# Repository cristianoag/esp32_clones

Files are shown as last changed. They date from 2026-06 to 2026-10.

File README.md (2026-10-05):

# The Retro Hacker Clone Series

The Retro Hacker Clone Series brings together hardware designs and source-available firmware to recreate and emulate classic Brazilian computers from the 80s using modern ESP32-S3 based hardware.

 The board is designed to feel like a small retro computer rather than a bare dev board, and the firmwares are built to be practical, tweakable, and easy to build from a standard Git checkout.

At the moment the series includes four emulator builds on the same ESP32-S3 board:

| Firmware | Covered machines | Project |
| --- | --- | --- |
| CP400 | Prologica CP400 / CoCo 2 | [Setup guide](software/esp32_cp400_emulator/README.md) and [change log](software/esp32_cp400_emulator/docs/log.md) |
| MSX | MSX1, MSX2, and MSX2+ | [Setup guide](software/esp32_msx_emulator/README.md) and [change log](software/esp32_msx_emulator/docs/log.md) |
| TK90X / TK95 | Microdigital TK90X (48 KiB) and TK95 | [Setup guide](software/esp32_tk95_emulator/README.md) and [change log](software/esp32_tk95_emulator/docs/log.md) |
| Apple II | Generic Apple II+ and original Apple IIe | [Setup guide](software/esp32_apple2_emulator/README.md) and [change log](software/esp32_apple2_emulator/docs/log.md) |

All four builds share the same board, VGA output, USB keyboard input, SD-card storage, and a simple F12 menu for setup and firmware updates.

### Switching emulators

With the current updater and shared dual 4 MiB OTA layout installed, open
**F12 > Firmware update** in any emulator and select another emulator's
`.FLH` package. For example, MSX can install CP400, and CP400 can then
install Apple II. No renaming is needed. Copy the packages to the FAT32
card root (required by CP400's file picker), prepare the destination
emulator's ROMs using its setup guide, confirm the update and keep power
connected until the board restarts. The original FLH stays on the card.

Build packages with `make firmware` in each firmware folder. Older MSX,
TK and Apple updaters reject other emulator filenames: first update to
the current build of the **same** emulator. Older CP400 installations use
a smaller partition layout and require a **one-time UART upload** of a
current build before switching via SD. FLH updates replace only the
application, not the bootloader or partition table. Use current builds
for every destination so switching remains available after reboot.
Checksums detect corruption, not authenticity; install only trusted
firmware built for this board.

After building all four packages, run
`powershell -ExecutionPolicy Bypass -File .\software\Test-FirmwareCompatibility.ps1`
to check the shared layout and all 16 source/destination combinations
against mock OTA storage. Physical-board switching still needs validation.

## Why this exists

The goal is not to produce a display piece. This is meant to be a useful, buildable retro-computing emulation based platform: something that captures the character of a Brazilian 80s machine without needing a pile of original hardware on the bench.

The project sits between hardware design, emulator work, and preservation. It keeps the board layout, software, and documentation together in one place so someone can build, test, and modify it without digging through a dozen disconnected repos.

## CP400

The Prologica CP400 was one of the more recognizable Brazilian home computers of the 1980s. It was compatible with the Tandy/Radio Shack TRS-80 Color Computer 2, but it had its own industrial design, Brazilian-language software ecosystem, and local hardware expectations.

The [CP400 firmware](software/esp32_cp400_emulator/README.md) recreates that environment on ESP32-S3 hardware, including MC6809 emulation, VGA output, native USB keyboard support, joystick inputs, SD storage, virtual floppy handling, and the F12 configuration/update menu.

## MSX

The MSX has a very special place in Brazilian computing history. It officially arrived in Brazil in 1985 through two locally produced machines: the HotBit, from Sharp/Epcom, and the Expert, from Gradiente. At a time when Brazil’s computer market was heavily restricted and imported machines were difficult and expensive to obtain, the MSX became one of the country’s most important home-computing platforms. Its standardized architecture, large software library, expandability, and built-in BASIC introduced an entire generation not only to games, but also to programming, electronics, and computer technology. 

The [MSX firmware](software/esp32_msx_emulator/README.md) runs the original fMSX core on the same shared board. It includes multiple BIOS profiles for Omega MSX2+, Gradiente Expert 1.1, Sharp Hotbit 1.2, and Panasonic FS-A1WSX / FS-A1F / FS-A1FX.

The software supports the core MSX experience with USB keyboard input, graphics, sound, cartridge booting, and firmware updates through the on-screen menu. and... USB joystick support, of course.

The F12 Media menu attaches writable `.dsk` images to drives A/B and read-only `.cas` tapes, with ejection, tape rewind and optional saved boot defaults. Disk access requires a compatible user-supplied disk BIOS; see the [disk and tape setup guide](software/esp32_msx_emulator/README.md#disk-and-tape-images).

## TK90X / TK95

The Microdigital TK90X and TK95 brought the ZX Spectrum family of computers to Brazilian homes. The [TK firmware](software/esp32_tk95_emulator/README.md) emulates the TK95 and 48 KiB TK90X on the same shared ESP32-S3 board, using
the cycle-stepped chips Z80 core.

The firmware includes VGA output, USB keyboard input, beeper audio and two USB joystick ports with calibration and selectable Kempston, Sinclair 1/2 or Cursor interfaces. The F12 menu brings together machine and ROM selection, 50/60 Hz Microdigital ULA timing, Portuguese/Spanish ROM language selection, sound and volume, saved boot defaults, reset options and firmware updates.

Media support includes read-only standard `.tap` playback and loading 48K `.sna` and `.z80` snapshots. Supply legally obtained, raw 16 KiB ROMs at `tk\bios\tk95.rom` and `tk\bios\tk90.rom` on the FAT32 card; the `tk` folder can sit alongside `msx` and `cp400`. No ROM bytes are embedded in the firmware.

See the [SD card and ROM setup](software/esp32_tk95_emulator/README.md#sd-card-and-roms) and [keyboard guide](software/esp32_tk95_emulator/README.md#keyboard-and-joysticks) for the original TK keyword-entry conventions.

The initial release does not include AY audio, Betadisk, TZX, tape recording or snapshot saving, and does not claim full cycle accuracy. 

## Apple II

The [Apple II firmware](software/esp32_apple2_emulator/README.md) adds generic
Apple II+ (64 KiB with language card) and original Apple IIe (128 KiB)
profiles. It follows the shared standalone PlatformIO, board-driver, F12
configuration and FLH firmware-update conventions.

The initial integration uses
[codesafe/ESP32-VGA_AppleII_Emulator](https://github.com/codesafe/ESP32-VGA_AppleII_Emulator)
as its starting reference, with a cycle-stepped NMOS 6502 and additional
IIe banking and display support. VGA preserves the full width of
80-column text; USB keyboard, calibrated joystick/paddle input, speaker
audio and two read-only NIB Disk II drives are included.

Supply machine and Disk II ROMs under `apple2/bios` on SD. No ROMs or games
are distributed. Enhanced IIe/65C02 and Brazilian TK2000, TK3000/Compact,
MC-4000/Exato and Exato IIe profiles are not claimed as supported without
their required hardware and verified ROMs. See the
[scope and limitations](software/esp32_apple2_emulator/README.md#supported-media-and-limitations).
Physical-board validation is still pending.

## Repository layout

```text
hardware/esp32_clones/          KiCad PCB and shared board files
hardware/esp32_clones/libraries Local KiCad symbols and footprints
hardware/esp32_clones/bom       Interactive BOM and BOM assets
hardware/cases/standard/       Parametric printed base, acrylic lid and manufacturing exports
software/esp32_cp400_emulator/  PlatformIO firmware for the CP400 build
software/esp32_msx_emulator/    MSX firmware and setup files
software/esp32_tk95_emulator/   TK90X/TK95 firmware and setup files
software/esp32_apple2_emulator/ Apple II+/original IIe firmware and setup files
images/                         Generated images and project documentation assets
```

## Board renderings

For the first enclosure prototype, see the
[standard case manufacturing files and engineering report](hardware/cases/standard/README.md).
It combines a printed base with side-loading M3 PCB nut traps, a snap-fit upper
shell, and a plain 3 mm acrylic lid seated in a recess. The report documents the
remaining physical-fit checks for components missing from the board STEP.

The Hotbit-inspired **Compact Classic C2** fits the same PCB in a
**124 x 74 x 39.1 mm** case, reducing the earlier Classic footprint by 26.9%.
It retains the miniature keyboard, photo-inspired colours and closed decorative
grille, with underside M3 cover screws. Use the matching
[base STL](hardware/cases/hb-8000/classic_base.stl) and
[upper STL](hardware/cases/hb-8000/classic_upper.stl); do not mix these with older
Classic or Wasteland halves. See the
[assembled/exploded preview](hardware/cases/hb-8000/classic_preview.png).
Print both STLs at 100%; the upper needs removable interior supports.
PCB screws remain M3 x 8 with 1 mm nylon washers; cover screws are M3 x 16,
with four M3 hex nuts for each set. Physical plug-fit and thermal tests are
still required; the decorative grille is not a ventilation opening.

The PCB below is the current KiCad board layout for the shared ESP32 clone board. The front and back views are generated directly from the project PCB.

<div align="center">
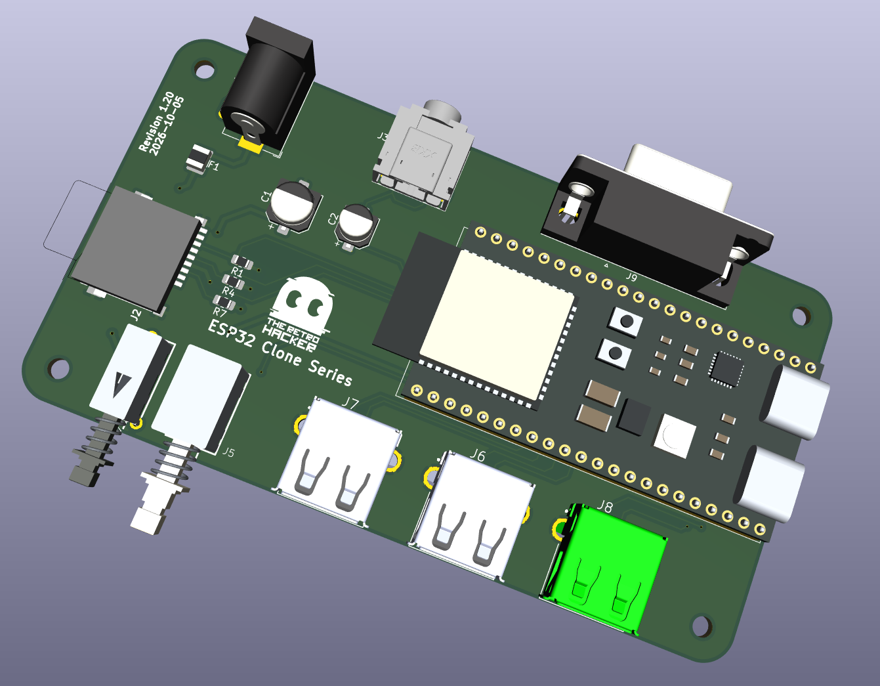
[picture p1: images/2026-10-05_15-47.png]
ESP32 clone board front
  
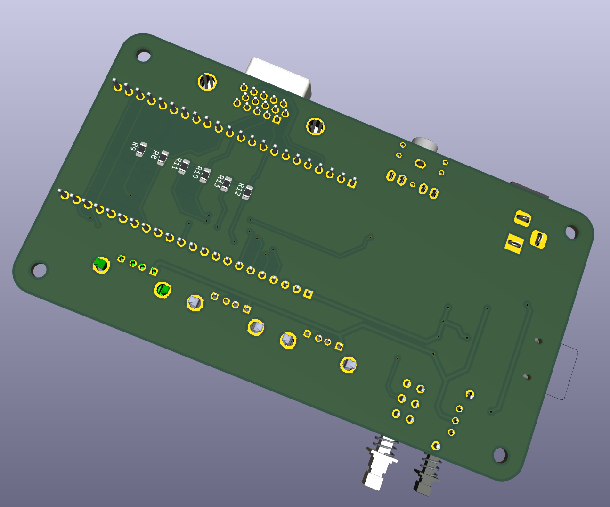
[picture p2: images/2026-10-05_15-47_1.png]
ESP32 clone board back
  
</div>

For the full component-by-component assembly view, open the [interactive BOM](https://htmlpreview.github.io/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).

## Hardware summary

The board is built around an ESP32-S3 DevKitC-style N16R8 module with 16 MB flash and 8 MB OPI PSRAM. It includes VGA output, a USB keyboard port, SD/MMC storage, a mono audio output, and a compact layout intended to behave more like a small computer than a bare dev board.

The shared board is used by all four firmware projects, and the pin mapping is documented in the [MSX hardware section](software/esp32_msx_emulator/README.md#hardware), the [TK hardware section](software/esp32_tk95_emulator/README.md#hardware) and the [Apple II hardware section](software/esp32_apple2_emulator/README.md#hardware).

## BOM and purchasing

This is the current BOM for the board as defined in the KiCad project. The table is meant to be a quick parts reference for ordering and build prep.

| Component | Description | Qty | Package | AliExpress |
| --- | --- | ---: | --- | --- |
| C1 | 220 µF electrolytic capacitor | 1 | 6.3x3 mm | [AliExpress](https://s.click.aliexpress.com/e/_c3vZZzuN) |
| C2 | 10 µF electrolytic capacitor | 1 | 5x4.5 mm | [AliExpress](https://s.click.aliexpress.com/e/_c3vZZzuN) |
| C4 | 100 nF ceramic capacitor | 1 | 0805 | [AliExpress](https://s.click.aliexpress.com/e/_c31gzw17) |
| C6 | 47 nF ceramic capacitor | 1 | 0805 | [AliExpress](https://s.click.aliexpress.com/e/_c31gzw17) |
| F1 | Resettable fuse / polyfuse | 1 | 1210 | [AliExpress](https://s.click.aliexpress.com/e/_c36cHi81) |
| J1 | DC barrel jack | 1 | Horizontal | [AliExpress](https://s.click.aliexpress.com/e/_c3D102dx) |
| J2 | Micro SD card socket | 1 | uSD | [AliExpress](https://s.click.aliexpress.com/e/_c3odXI41) |
| J3 | 3.5 mm audio jack | 1 | PJ-307 | [AliExpress](https://s.click.aliexpress.com/e/_c4DX94lF) |
| J4 | 12V power header / connector | 1 | PS-12E05 | [AliExpress](https://s.click.aliexpress.com/e/_c42cnGRn) |
| J5 | 5V power header / connector | 1 | PS-22F05 | [AliExpress](https://s.click.aliexpress.com/e/_c35YnsCh) |
| J6–J8 | USB-A connector | 3 | TE 6364372-2 | [AliExpress](https://s.click.aliexpress.com/e/_c4afTAHb) |
| J9 | DB15 video connector | 1 | D-sub 15-pin | [AliExpress](https://s.click.aliexpress.com/e/_c3K7eRWv) |
| R1, R4, R7 | 10 kΩ resistor | 3 | 0805 | [AliExpress](https://s.click.aliexpress.com/e/_c2zrvGiH) |
| R8, R10, R12 | 1.2 kΩ resistor | 3 | 0805 | [AliExpress](https://s.click.aliexpress.com/e/_c2zrvGiH) |
| R9, R11, R13 | 560 Ω resistor | 3 | 0805 | [AliExpress](https://s.click.aliexpress.com/e/_c2zrvGiH) |
| R2, R5 | 330 Ω resistor | 2 | 0805 | [AliExpress](https://s.click.aliexpress.com/e/_c2zrvGiH) |
| U1 | ESP32-S3-WROOM-1 module | 1 | ESP32-S3-WROOM-1 | [AliExpress](https://s.click.aliexpress.com/e/_c2uppnEv) |

## Firmware build notes

All three firmware projects use PlatformIO with the Arduino framework and a pinned `espressif32@6.11.0` platform. From the project directory you want to use, run:

```powershell
Set-Location .\software\esp32_cp400_emulator
# or:
# Set-Location .\software\esp32_msx_emulator
# or:
# Set-Location .\software\esp32_tk95_emulator

make firmware
```

The build produces FLH packages for each target; the project directories keep their own firmware images and configuration.
Each firmware directory includes its own board definitions and required
library sources and can be copied and compiled independently of the others.
All three still require PlatformIO and the configured ESP32 toolchain.

## ROMs and original software

Original CP400, CoCo, MSX, TK90X/TK95, ZX Spectrum, BASIC, cartridge, cassette, and floppy software may still be copyrighted. This repository is for original hardware, firmware, and project files. Use legally obtained ROMs and software images when needed.

The CP400 firmware loads its BIOS files from `software/esp32_cp400_emulator/sdcard/cp400/bios`. Copy the `cp400` folder to the root of the microSD card so the firmware can read the BASIC, Extended BASIC, and CP400 or CoCo disk controller ROM selected in the F12 menu.

## Historical notes

The CP400 was part of the wider Brazilian TRS-Color ecosystem, the MSX line became one of the most important home computer families in Brazil, and Microdigital's TK90X and TK95 connected Brazilian users to the ZX Spectrum ecosystem. This project sits at the intersection of those histories: a practical board, three emulator builds, and a small bit of preservation work for machines that still matter to a lot of people.

## References

- [Prologica CP-400](https://en.wikipedia.org/wiki/Prol%C3%B3gica_CP-400)
- [CP400](https://pt.wikipedia.org/wiki/CP400)
- [TRS-80 Color Computer](https://en.wikipedia.org/wiki/TRS-80_Color_Computer)
- [MSX](https://en.wikipedia.org/wiki/MSX)
- [fMSX by Marat Fayzullin](https://fms.komkon.org/fMSX/)
- [TK90X](https://en.wikipedia.org/wiki/TK90X)
- [TK95](https://en.wikipedia.org/wiki/TK95)
- [ESPectrum reference emulator](https://github.com/EremusOne/ESPectrum)
- [chips Z80 core](https://github.com/floooh/chips)
- [Prologica](https://pt.wikipedia.org/wiki/Prol%C3%B3gica)
- [Datassette](https://datassette.org/)

## License



All hardware and firmware binaries in this repository are released under the Creative Commons Attribution-NonCommercial-ShareAlike 4.0 International license. Personal builds and community tinkering are encouraged, but commercial use or resale requires explicit authorization from the author.

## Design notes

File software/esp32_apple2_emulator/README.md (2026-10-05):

# ESP32 Apple II+ / original Apple IIe

Standalone firmware for the shared Retro Hacker Clone Series ESP32-S3 N16R8
board. Firmware version: **1.03**. The CP400, MSX and TK firmware folders are
not needed to build or run it.

The initial profiles are **generic Apple II+** (48 KiB RAM plus a 16 KiB
language card) and **original Apple IIe** (128 KiB including the extended
80-column card). Both use a cycle-stepped **NMOS 6502**, not a 65C02.
Default: original IIe.

[codesafe/ESP32-VGA_AppleII_Emulator](https://github.com/codesafe/ESP32-VGA_AppleII_Emulator)
is the initial reference. Its II+ hardware is not sufficient for an IIe:
this integration adds IIe banking, internal firmware selection, 80-column
text and double-resolution graphics. The CPU is the licensed chips 6502,
following the TK firmware's cycle-stepped-core pattern. See
[dependency provenance](lib/README.md).

**Brazilian clone profiles are deferred.** TK2000 is not simply an Apple II
ROM replacement; TK3000 IIe/Compact require enhanced-machine and
clone-specific support. MC-4000/Exato and Exato IIe also need their own
verified ROMs and hardware profiles. They are not listed as supported
machines merely because they belong to the Apple family.

## Hardware

| Function | GPIO |
| --- | --- |
| VGA red low/high | 5 / 4 |
| VGA green low/high | 7 / 6 |
| VGA blue low/high | 9 / 8 |
| VGA HSYNC / VSYNC | 2 / 1 |
| Native USB keyboard D- / D+ | 19 / 20 |
| Low-speed USB joystick 1 D- / D+ | 15 / 16 |
| Low-speed USB joystick 2 D- / D+ | 17 / 18 |
| One-bit SD/MMC CMD / CLK / D0 | 38 / 39 / 40 |
| Mono PWM audio | 47 |
| Onboard RGB LED, disabled at startup | 48 |

Use the board's **UART connector** for upload and diagnostics. Native USB
is reserved for the keyboard; the board must supply VBUS. Joysticks use
the existing direct low-speed USB transport, not hubs or full-speed pads.

VGA uses a **640x240 framebuffer with hardware line doubling**. The
560x192 Apple picture is centered: 40-column text and 280-pixel graphics
are doubled horizontally; 80-column text and 560-pixel graphics retain
their full horizontal resolution. The F12 UI retains the familiar
320x240 logical layout. Set a widescreen monitor to 4:3/aspect mode.
The pinout and physical VGA timing remain compatible with the shared board.

## Build, test and upload

From this firmware directory:

```powershell
pio run
make test
make firmware
pio run -t upload
```

PlatformIO is pinned to `espressif32@6.11.0`. `make` finds PlatformIO's
usual Windows virtual environment. Native tests require G++ and
PowerShell on PATH. All libraries and the board definition are local.

`make firmware` packages and verifies `dist\ESP32_APPLE2-1.03.FLH` using
the shared decimal checksum + `-~` + ESP32-S3 application format.
Install over UART first to install the dual 4 MiB OTA partition layout.
Later updates use **F12 > Firmware update** and any compatible `.FLH`
package for CP400, MSX, TK95 or Apple II on SD, without renaming. Prepare
the destination emulator's ROMs before switching and put packages at the
card root so CP400's file picker can also find them. After restart, use
the destination's Firmware update menu to switch again.
The checksum is **not a signature**; use only trusted firmware for this
board. Keep power connected throughout; the original FLH is preserved.
An older Apple updater must first install the current Apple package to
remove its filename restriction. Older CP400 layouts require a one-time
UART upload of a current build; FLH cannot change the partition table.
Use current destination builds to retain cross-emulator updates.

## SD card and ROMs

Use FAT32 and put `sdcard\apple2` at the card root. It can coexist with
`cp400`, `msx` and `tk`:

```text
apple2\
  bios\
    apple2plus.rom    12,288 bytes, D000-FFFF
    apple2e.rom       16,384 bytes, C000-FFFF, ORIGINAL IIe
    disk2.rom            256 bytes, slot 6, 16-sector Disk II P5 ROM
  disks\
    your-disk.nib    232,960 bytes
```

Supply legally obtained raw binary dumps. No ROMs, character ROMs, games
or disk images are distributed. Only the selected machine ROM and the
Disk II ROM are required. A combined II+ dump must contain the six
2 KiB ROMs in ascending CPU-address order. The IIe dump must contain the
two 8 KiB halves in ascending CPU-address order. An enhanced IIe ROM is
the same size but requires a 65C02 and is **not supported**.

The import helper checks sizes and verifies copies:

```powershell
.\tools\Import-Roms.ps1 -Destination .\sdcard `
    -IIPlusRom 'C:\roms\appleII+.rom' `
    -IIeRom 'C:\roms\appleIIe.rom' `
    -DiskRom 'C:\roms\diskII.rom'
```

Either machine ROM argument can be omitted. Size validation does not
identify arbitrary ROM contents. Configuration has separate remembered
ROM paths per model and a shared slot-6 ROM path. A file browser can
select ROMs elsewhere on the card.

Without a disk in drive 1, the real Disk II boot firmware waits for media.
Use **F12 > Warm reset** to enter BASIC after the initial boot. To boot a
disk, mount it in drive 1 and select cold boot.

From the BASIC prompt, `PR#6` also boots drive 1. Disk II emulates the
hardware's one-second motor-stop delay, allowing DOS to keep the drive
spinning between sector reads. Firmware 1.00 stopped it immediately,
causing repeated spin-up waits that made games such as Karateka appear
frozen. Update to 1.01 or later if you encounter that symptom. Loading
still takes emulated disk time rather than starting instantly.

## F12 workflow

F12 pauses the CPU, disk emulation and sound. Esc goes back one page;
F12 resumes from ordinary submenus. Confirmations default to cancellation:
**Y** confirms; **N/Esc/F12** cancels.

| Page | Features |
| --- | --- |
| Configuration / ROM | II+/IIe, machine and Disk II ROMs, sound/volume, auto boot, frame skipping, color/green monitor, save/reboot |
| Media / Disk II drives | Mount two read-only NIBs, Delete to eject, save complete boot configuration, reboot with/without saving |
| USB joysticks | Enable/disable each port, seven-step calibration, live input, clear calibration |
| Warm reset | Retain RAM and mounted disks; reset CPU and soft switches |
| Cold boot | Validate selected files, apply pending machine/ROM selection, clear RAM and reset disk heads |
| Retry microSD | Retry an initially failed mount |
| Firmware update | Browse, confirm, validate, install and restart |
| Hardware / help | Wiring, controls and boot instructions |

Arrows navigate; Enter selects; Left/Right changes settings. Browsers
traverse directories, filter extensions case-insensitively and use
Page Up/Down for ten-entry pages. Unsupported/overlong paths are reported.
There is a 2.5-second F12 window before automatic boot.

Machine and ROM changes are **pending until cold boot**. Resuming and warm
reset keep the running ROM/model. Disk mount/eject takes effect on resume
without rebooting; inserting a boot disk alone does not restart the CPU.
Failed validation preserves the old attachment and running state.

Saving validates the selected boot files and stores both machine ROM
paths, slot ROM, both disk paths, sound, volume, auto boot, frame skipping,
monitor color and joystick enable flags in Apple-specific NVS.
Calibration is stored separately in its own Apple namespace.

Keep SD inserted. Restart the board after replacing a mounted card.
Initialization, SD, allocation and NVS failures are reported on VGA/UART.

## Keyboard, paddles and sound

Keyboard input uses the Apple ASCII latch and strobe, with queued press
edges and key repeat. Caps Lock starts **on**. Shift/Caps controls letter
case; Ctrl generates control codes. The layout is US ASCII.

| USB control | Apple action |
| --- | --- |
| Enter / keypad Enter | Return |
| Backspace / Left | Control-H |
| Right / Up / Down | Control-U / Control-K / Control-J |
| Esc / Tab / Delete | Escape / Tab / DEL |
| Left Alt / Right Alt | Open Apple / Solid Apple (pushbuttons 0/1) |
| Shift | Also exposes the third pushbutton input |
| F12 | Host menu only |

Calibrate each USB pad using neutral, up, right, down, left, A and B.
Port 1 drives paddles 0/1 and pushbuttons 0/1; port 2 drives paddles 2/3
and the shared third pushbutton (either fire button). Directional input
maps to minimum/center/maximum paddle positions, not continuous analog
axes. A port's disabled setting returns its joystick input to neutral.

Speaker soft-switch accesses generate 22,050 Hz mono samples. The
shared GPIO47 PWM driver implements volume, pause/mute and idle silence.

## Supported media and limitations

- Two **read-only 35-track NIB** drives in slot 6. Images must be exactly
  35 x 6,656 bytes and contain nibblized disk bytes with bit 7 set.
  Write protection is reported to the emulated controller; writes never
  modify the image or SD. No `.dsk`, `.do`, `.po`, WOZ, cassette or snapshots.
- 40/80-column text, inverse/flashing characters, both display pages,
  lo-res, hi-res, mixed modes and IIe double lo-res/hi-res.
  Text uses the existing Adafruit ASCII font fitted to 7x8 cells, **not**
  an Apple character-ROM reproduction. No MouseText or localized clone glyphs.
- IIe main/aux read/write banking, ALTZP, 80STORE, language-card banks,
  internal Cx/C8 ROM switching and original 80-column ROM entry points.
- NTSC-like fixed CPU/frame timing. Video is rendered at frame boundaries;
  artifact colors, floating-bus timing and disk rotation are approximations.
  No claim of cycle-perfect video, copy-protection compatibility or full
  hardware equivalence. The 6502 itself is cycle-stepped.
- No enhanced IIe/65C02, IIc/IIgs, CP/M/Z80 card, Mockingboard, printer,
  serial cards, extra RAM cards or verified Brazilian clone profiles.

## Performance diagnostics

The CPU targets about 60 emulated frames per second. A disk that takes
35 emulated seconds takes about 70 wall-clock seconds at 30 fps, or
105 seconds at 20 fps. Firmware 1.01 was measured on the board at about
20 fps rendering every frame and 30.6 fps rendering every third frame.
Those rates are slow emulation, not evidence that the CPU has frozen.

Version 1.02 placed the 6502 decoder and memory-access hot path in
internal instruction RAM, avoids unused floating-bus calculations during
disk reads, renders scanlines in internal RAM before copying to PSRAM,
and skips unchanged display frames. Flashing text, video-mode/page
changes and writes to either display bank still trigger redraws. It keeps
the 640x240 framebuffer and full-width 80-column output.

On-board 1.02 measurements then isolated about 20.6 ms of CPU work per
emulated frame, plus about 7.3 ms of averaged video/copy work at 1/3
rendering. Resolution alone cannot meet a 16.6 ms frame budget while CPU
work exceeds it.

Version 1.03 uses precomputed RAM/ROM page mappings and an inlined bus
loop, preserving the same cycle and soft-switch behavior. It streams
internal-RAM scanlines straight into the VGA DMA framebuffer, eliminating
the extra 150 KiB PSRAM framebuffer and its copy. Writes to memory that
does not contribute to the cached screen no longer force a redraw; this
avoids repainting text while DOS loads graphics into unrelated RAM.
Resolution and 80-column support are unchanged.

UART logs now split average time per emulated frame into **CPU**, **video**,
**copy** and **audio** milliseconds, and include actual redraw count,
CPU PC, drive-1 track and elapsed emulated time. Video/copy averages include
skipped frames, not just rendered ones. Startup also reports internal
heap headroom. Capture several steady-state lines; the initial boot phase
is not representative of game speed. Version 1.03 still requires fresh
on-board measurements before claiming full-speed operation.

## Validation

`make test` uses synthetic data only: CPU decimal arithmetic, bank
selection, language-card write protection, keyboard/paddles, bounded NIB
access, write-protected media, video layout, audio sample counts, settings,
joystick calibration and FLH validation/failure paths.

With user-supplied ROMs in the default SD layout, run `make test-roms`.
Alternative paths can be passed to `tools\Test-Roms.ps1` with
`-IIPlusRom`, `-IIeRom` and `-DiskRom`. This boots both profiles, evaluates
BASIC expressions, checks actual output in 80-column memory, and boots
an original synthetic NIB sector through the Disk II ROM.

An optional test uses your local Karateka NIB (not distributed):

```powershell
.\tools\Test-Roms.ps1 -KaratekaDisk .\sdcard\apple2\disks\karateka.nib
```

This validates the reported disk revision by SHA256, then checks cold
boot and `PR#6` on both machines. The intro must be visible within 60
emulated seconds, and Space must advance into the game within a further
60 seconds. It does not change the disk image.

Host regression tests, ROM smoke tests and the ESP32-S3 build/package
were verified during integration. Physical VGA/USB/audio/SD operation
and sustained real-time speed still require testing on the board.

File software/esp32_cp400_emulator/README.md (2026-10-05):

# ESP32 CP400 / CoCo 2

This is the Prologica CP400 / CoCo 2 firmware for the Retro Hacker Clone
Series ESP32-S3 N16R8 board. It includes MC6809 emulation, VGA, a native
USB keyboard, two USB joystick ports, mono audio, microSD disk images
and an F12 configuration/update menu.

## Hardware

| Function | GPIO |
| --- | --- |
| VGA red, low/high bits | 5 / 4 |
| VGA green, low/high bits | 7 / 6 |
| VGA blue, low/high bits | 9 / 8 |
| VGA HSYNC / VSYNC | 2 / 1 |
| USB keyboard D- / D+ | 19 / 20 |
| USB joystick 1 D- / D+ | 15 / 16 |
| USB joystick 2 D- / D+ | 17 / 18 |
| SD/MMC CMD / CLK / D0 | 38 / 39 / 40 |
| Mono PWM audio | 47 |
| Onboard RGB LED | 48 |

Use a directly connected USB HID keyboard. The native USB controller is
reserved for the keyboard; uploads and serial diagnostics use the UART
port. SD uses one-bit SD/MMC, not SPI.

## Build and upload

From this firmware directory:

```powershell
make firmware
make test
make upload
```

PlatformIO is pinned to `espressif32@6.11.0`. `make` finds PlatformIO's
usual Windows virtual environment and exports the firmware version.
Packaging requires Python; host tests require PowerShell and native G++.
Set the upload and monitor ports in [platformio.ini](platformio.ini) to
the board's UART port before using `make upload`.

`make firmware` builds and verifies `dist\ESP32_CP400-1.13.FLH`.
The board definition, libraries and updater are local, so this folder
remains independently buildable. The updater follows the same validated
FLH/OTA implementation as the other clone-series firmware projects.

## SD card and ROMs

Use FAT32. Supply legally obtained raw ROM dumps under `cp400\bios`:

| File | Size | Use |
| --- | --- | --- |
| `extbas11.rom` | 8,192 bytes | Extended BASIC |
| `bas13.rom` | 8,192 bytes | BASIC |
| `cp400dsk.rom` | 8,192 bytes | CP400 disk controller |
| `disk11.rom` | 8,192 bytes | CoCo 2 disk controller |

The first two files and the selected disk controller ROM are required.
Missing, unreadable or wrong-sized ROMs stop startup with a UART error.
Prepare these files before switching to CP400 from another emulator.
The `cp400` folder can coexist with `msx`, `tk` and `apple2` on one card.
ROMs and games are not distributed with the firmware.

Put `.DSK` images at the card root. **F12 > Disk drives** assigns them
to the four virtual drives; Delete ejects the selected disk and saves
the empty assignment. F12 also provides Disk ROM selection, artifact
colors, joystick calibration, reboot and firmware updates.

## Firmware updates and switching emulators

Open **F12 > Firmware update**, select a `.FLH` file at the card root
and confirm with Y. CP400 accepts CP400, MSX, TK95 and Apple II packages
without renaming. The destination emulator starts after installation;
use its Firmware update menu to switch again. Prepare its ROMs first.

The updater checks the shared partition layout, file structure, checksum,
ESP32-S3 image header and 4 MiB image limit before writing the inactive
OTA slot. A second pass detects changes during the update; ESP-IDF
verifies the image before selecting it for boot. Failures are reported
on screen and UART without intentionally restarting or selecting the
failed image. Successful updates preserve the source FLH file.
Keep power connected throughout. A checksum is not a signature: use
only trusted firmware for this board.

**Older CP400 installations require one UART upload with `make upload`**
to replace the old small-slot partition table with the shared dual
4 MiB layout. Updating with FLH alone cannot migrate that table.
Boards already running current MSX, TK or Apple firmware on the shared
layout can install this CP400 package directly. Use current builds of
all destinations to retain cross-emulator updates.

See the [firmware change log](docs/log.md) for version history.

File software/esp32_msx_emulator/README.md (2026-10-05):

# ESP32 MSX / fMSX

This is the MSX firmware for the Retro Hacker Clone Series board. It uses the original fMSX core and targets the shared ESP32-S3 N16R8 hardware used by the rest of the project.

## Hardware

The hardware layout matches the shared board used by the CP400 project and is documented here for reference.

| Function | GPIO |
| --- | --- |
| VGA red, low/high bits | 5 / 4 |
| VGA green, low/high bits | 7 / 6 |
| VGA blue, low/high bits | 9 / 8 |
| VGA HSYNC / VSYNC | 2 / 1 |
| USB keyboard D- / D+ | 19 / 20 |
| USB joystick 1 D- / D+ | 15 / 16 |
| USB joystick 2 D- / D+ | 17 / 18 |
| SD/MMC CMD / CLK / D0 | 38 / 39 / 40 |
| Mono PWM audio | 47 |
| Onboard RGB LED | 48 |

SD uses a one-bit SD/MMC interface rather than SPI. Connect a USB HID keyboard directly to the keyboard port, and use the board's UART port for upload and diagnostics. The native USB controller is reserved for the keyboard.

The firmware is self-contained: its board definition lives in `boards`, and
its VGA, Adafruit GFX, BusIO and USB transport sources live in `lib`.
The entire `esp32_msx_emulator` folder can be copied and built on its own;
the CP400 firmware folder is not required. PlatformIO and the pinned ESP32
platform/toolchain are still required.

The local dependency copies preserve their original versions, copyright
notices and licenses. See [dependency provenance](lib/README.md).

## Build

From this firmware directory, run `pio run` to build or `make firmware` to
build, package and verify `dist\ESP32_MSX-1.01.FLH`. The same commands work
when this folder is outside the clone-series repository. `make test` runs
the host regression tests using PowerShell and native G++.

If updating an older checkout that used cross-project symlinks, PlatformIO
normally removes obsolete dependencies during the next build. If local
cache metadata still points to the old project, delete this firmware's
generated `.pio` directory and rebuild; no CP400 files need to be changed.

## Firmware updates and switching emulators

With the shared dual 4 MiB OTA layout installed, **F12 > Firmware update**
accepts `.FLH` packages for CP400, MSX, TK95 and Apple II without renaming.
Copy a trusted package to the FAT32 card root, prepare the destination's
ROMs, select the file, confirm and keep power connected until restart.
Use the destination's Firmware update menu to switch again.

The updater validates the package, ESP32-S3 image and size before writing,
checks a second pass and selects the inactive slot only after ESP-IDF
image verification. The original FLH remains on SD. The checksum is not
a signature; unrelated ESP32-S3 firmware is not necessarily compatible.

An older MSX updater must first install the current MSX package to remove
its filename restriction. Old CP400 partition layouts require a one-time
UART upload of a current build; FLH does not replace the partition table.
Always use current destination builds to retain cross-emulator updates.

## Prepare the SD card

Use a FAT32 card. BIOS files are supplied by the user and loaded from SD rather than being built into the firmware. From this firmware directory:

```powershell
.\tools\Import-Roms.ps1 -Destination .\sdcard `
    -OmegaRom 'C:\path\to\omega_msx2+_all_ntsc.bin' `
    -ExpertRom 'C:\path\to\expert_1.1_basic-bios1.rom' `
    -HotbitRom 'C:\path\to\hotbit_1.2_basic-bios1.rom'
```

Copy the generated `sdcard\msx` folder to the card root. Alternatively, use the SD drive root as the destination.

The initial profiles are:

| Profile directory | Machine | Default RAM | BIOS files |
| --- | --- | --- | --- |
| `msx\bios\omega` | MSX2+ | 512 KiB | `OMEGA.ROM` |
| `msx\bios\expert` | Gradiente Expert 1.1 / MSX1 | 64 KiB | `MSX.ROM` |
| `msx\bios\hotbit` | Sharp Hotbit 1.2 / MSX1 | 64 KiB | `MSX.ROM` |
| `msx\bios\fs-a1wsx` | Panasonic FS-A1WSX / MSX2+ | 64 KiB | `PANASONIC.ROM` |
| `msx\bios\fs-a1f` | Panasonic FS-A1F / MSX2 | 64 KiB | `PANASONIC.ROM` |
| `msx\bios\fs-a1fx` | Panasonic FS-A1FX / MSX2+ | 64 KiB | `PANASONIC.ROM` |

## Media menu

Open **F12 > Media** to access cartridge slots 1 and 2, their mapper controls,
disk drives A and B, tape selection, rewind and reboot choices on one page.
Only **Audio** opens a configuration submenu; selecting a slot, drive or tape
opens its file browser directly. Audio applies to the whole machine.
Press Enter to browse for an image or Delete to eject the selected slot,
drive or tape. Esc goes back one menu level. From Media or Audio, F12
resumes a running machine directly.

### Cartridge ROMs and rebooting

In **Media**, select either or both cartridge slots, then choose:

- **Reboot and save configuration:** save the complete current boot
  configuration (BIOS, RAM, sound, auto-boot, both cartridges, both disks
  and tape, cartridge mapper overrides and the audio profile), then cold-boot with those selections.
- **Reboot without saving:** cold-boot with the selected configuration for
  this session without overwriting the saved defaults.

Both options discard the current emulated machine state. A validation or
save failure leaves the menu open and does not reboot. Cartridge insertion
and ejection take effect only on cold boot. Leaving F12 without choosing
a reboot option resumes with the previously running cartridges; your new
selections remain pending until a cold boot.

### Automatic cartridge mapper detection

After selecting a cartridge, the Media page shows its detected mapper and
the detection source. Select the **Mapper** row below either slot and use
Left/Right (or Enter) to cycle between **Auto** and the supported manual
mappers. Delete on a mapper row restores Auto; Delete on a slot row ejects
the cartridge. Replacing or ejecting a ROM resets that slot's override to
Auto; choosing the same file preserves its override.

The detected mapper remains visible even when you choose a manual override.
Inspection uses the selected BIOS profile's overrides without changing a
running machine. Overrides take effect only on cold boot and are saved with
the complete boot configuration. Older saved configurations migrate with
both slots set to Auto. Failed file reads or inspection leave the previous
cartridge and override selected.

Banked cartridges now use the same **full-ROM SHA-1 database-first approach**
as PicoVerse. The 3115-entry database is embedded in the firmware and shared
by all BIOS profiles; no external database or PicoVerse directory is needed.
PicoVerse mapper IDs are translated to fMSX's Konami SCC, Konami, ASCII8 and
ASCII16 IDs. The selected banked mapper is reported on UART.

Manual F12 mapper choices take priority. In Auto mode, existing profile-local
`CARTS.CRC` / `CARTS.SHA` overrides still take priority over the embedded database.
Unknown cartridges retain the existing fMSX heuristic and plain/planar ROM
handling. Identification does not add hardware emulation: recognized
ASCII16-X, Manbow2, NEO8 and NEO16 cartridges report an unsupported mapper
instead of silently pretending to be a supported type.
See [database provenance](lib/fmsx/MapperDatabase/README.md).

**Tiny Magic 1.1:** the verified 512 KiB ROM with SHA-1
`b9664e6094d8488e8e0b8103b1be5443d8da0cd0` now selects Konami SCC automatically,
instead of plain Konami. Host tests also found two independent setup
requirements: at least **128 KiB RAM** and an **MSX-MUSIC/FM BIOS**.
Panasonic profiles default to 64 KiB, so select the profile first, then
change RAM to 128 KiB or more and cold-boot. Omega's 512 KiB is sufficient.
Use the FM-PAC/MSX-MUSIC audio profile described below. The original 16 KiB
`fs-a1wsx_fmbasic.rom` also works as an MSX-MUSIC BIOS. Correct mapper
detection alone cannot resolve missing RAM or the game's
"No FM PAC nor MSX MUSIC detected" message.

### Audio profiles and FM-PAC / MSX-MUSIC

The **Audio profile** setting controls the emulated sound hardware:

- **Auto:** preserves the normal PSG/SCC setup and enables FM when a compatible BIOS is available.
- **PSG only**
- **PSG + SCC**
- **PSG + FM-PAC/MSX-MUSIC**
- **PSG + SCC + FM-PAC/MSX-MUSIC**

This is one machine-wide setting for cartridges, disks and tapes, not a
separate setting for every file. Changing it requires a **cold reboot**.
The Audio page offers reboot with or without saving the complete boot
configuration. Merely resuming F12 leaves the currently running audio
hardware unchanged. The main menu's Sound toggle remains the mute control.

FM profiles need a legally obtained FM BIOS on microSD; no BIOS bytes are
embedded in the firmware. Import a 64 KiB FM-PAC BIOS, such as your
`FMPCCMFC.BIN`, or a compatible 16 KiB MSX-MUSIC BIOS:

```powershell
.\tools\Import-AudioBios.ps1 -Rom 'C:\path\to\FMPCCMFC.BIN' -Destination .\sdcard
```

Copy the generated `msx\audio\FMPAC.ROM` to the same path on the card.
This shared BIOS is available to every machine profile; a profile-local
`msx\bios\<profile>\FMPAC.ROM` takes precedence. The importer verifies size,
identification header and the copied bytes. Use `-Force` only to replace an
existing imported audio BIOS intentionally.

Missing or incompatible FM BIOS files are reported before selecting or
booting a required FM profile. The real BIOS is mapped in a system slot,
leaving both user cartridge slots available. FM and SCC have separate mixer
channels when enabled together.

For **Tiny Magic**, keep the cartridge mapper on **Auto / Konami SCC**, choose
**PSG + FM-PAC/MSX-MUSIC** (or the combined profile), select at least **128 KiB
RAM**, then reboot. **Do not change its cartridge mapper to FM-PAC**: the ROM
banking hardware and the sound hardware are separate choices.

## Disk and tape images

Use **F12 > Media** to select directly:

- **Drive A** and **Drive B:** raw `.dsk` floppy images.
- **Tape:** an MSX `.cas` cassette image.
- **Rewind tape:** return the current tape to its beginning.

Put your legally obtained images anywhere on the FAT32 card, for example
`msx\disks` and `msx\tapes`. The browser traverses folders and matches file
extensions without regard to case. WAV audio recordings and compressed
archives are not supported.

Supported disks use 80 tracks, nine 512-byte sectors per track, and either
one side (360 KiB / 368640 bytes) or two sides (720 KiB / 737280 bytes).
Forty-track double-sided 360 KiB images and other geometries are not
supported. CAS images must start with the standard MSX cassette marker
`1F A6 DE BA CC 13 7D 74`; raw binary files renamed to `.cas` are rejected.

Select a drive or tape row and press Enter to browse. Select **<Eject media>**
or press Delete on the row to remove its image. When a machine is running,
successful attachments take effect when you resume emulation; no reset is
needed for disk swaps or loading a new tape. Press F12 from Media
to return directly to the running machine. Failed attachments leave the
previous media selected. When no machine is running, selections apply at
the next cold boot.

Disk images are **read/write**: Disk BASIC commands such as
`SAVE "A:PROGRAM.BAS"` or `SAVE "B:PROGRAM.BAS"`, and supported disk software,
write directly to the attached `.dsk` file on microSD. Each completed sector
is flushed and synchronized before success is reported. No extra F12 save
or ejection is needed to persist disk contents. Saving boot defaults only
remembers media paths; choosing "Reboot without saving" does not undo disk
writes.

**Back up your disk images before using them.** Files/SD cards that cannot be
opened for writing are rejected rather than silently mounted read-only.
Use separate images for A and B; mounting the same file in both drives is
rejected to prevent conflicting cached copies. Keep the card inserted, and
do not power off during a disk operation. A power failure or SD write error
can leave a partial sector or filesystem update, as on a real disk.
Write failures are reported to MSX software and on UART; further writes to
that drive are blocked until you reattach its image. Check/recover the image
on a PC if an operation failed.

Disk attachment reads the image in 4 KiB chunks through aligned internal
memory and yields between chunks so background tasks can run. If attaching
fails, the menu/UART reports the stage, byte offset and OS error, and the
previous disk remains attached. An SD/MMC `0x107` log means the card/host
transaction timed out, not that the DSK format is unsupported. Persistent
timeouts require checking the card, seating and board power; an image with
the right size cannot by itself rule out a physical SD problem.

Disk formatting and creating new blank images are not implemented; attach
an existing, correctly formatted 360/720 KiB image. CAS tapes remain
**read-only**, and cassette recording is not supported. Attaching an
image does not automatically issue `LOAD`, `RUN`, or a reset.
For a cassette BASIC program use the appropriate command, for example
`CLOAD` or `LOAD "CAS:"`, followed by `RUN`. Binary tapes typically use
`BLOAD "CAS:",R`; follow the software's original loading instructions.
Rewind before reloading the same tape after reaching its end.

Use **Save BIOS + slots + media as boot default** to retain image paths
across restarts. Only paths are saved, not tape position or disk contents;
tapes start at the beginning on a new boot. Older saved configurations
are preserved with the new media assignments initially empty.
Use **Boot BIOS + slots + media (cold reset)** to boot disk software that
requires a reset. Missing saved images produce a recovery error rather
than silently booting with different media.

Leave the SD card inserted while media is attached. F12 BIOS rescanning
does not remount the card while an emulator is running, so an open tape
stream or writable disk handle is not invalidated. Restart the board after physically replacing
the SD card.

Disk BASIC additionally requires a compatible disk BIOS in the selected
profile; a `.dsk` image is not itself that BIOS. If the current machine has
no disk BIOS, F12 reports it instead of claiming a working drive. A BIOS
file added to SD requires a cold boot before disk attachments can be used.

The tested disk BIOS is the user-supplied **Philips NMS8250** 16 KiB dump
`nms8250_disk.rom` (SHA-1 `c3efedda7ab947a06d9345f7b8261076fa7ceeef`).
Copy it unchanged as `DISK.ROM` inside each desired `msx\bios\<profile>`
directory, or add `-DiskBios 'C:\path\to\nms8250_disk.rom'` to the ROM
import command. The importer installs it in every profile imported by that
command; use `-Force` only when intentionally replacing existing imports.
The importer checks size, not compatibility of arbitrary disk BIOS files.

This adds a compatible BIOS-backed disk interface to all six profiles,
including the Panasonic profiles, without replacing their startup/BASIC
ROMs. It does **not** emulate Panasonic's TC8566AF controller or its
built-in applications; the original Panasonic disk ROMs are not supported
replacements. From Disk BASIC, use `FILES "A:"` / `FILES "B:"` to list the
images, and normal disk loading commands such as `LOAD "A:PROGRAM.BAS"`.

## Notes

VGA uses the performance-oriented **320x240** framebuffer and lower pixel
clock, with hardware line doubling. The MSX picture still fills the 4:3
display width instead of sitting inside extra side bars. F12 uses its native
320x240 layout. The 640x480 rendering experiment was reverted after it slowed
games on the board.
If your monitor is widescreen, select its **4:3/aspect** display setting
rather than stretching the VGA signal to the whole panel.

MSX2/MSX2+ 80-column text is still available through `SCREEN 0:WIDTH 80`,
but uses the original reduced-resolution renderer: pairs of font dots are
merged, so it is less sharp than the high-resolution version. Use
`SCREEN 0:WIDTH 40` when readability matters. This deliberately prioritizes
game speed; the smaller core image, VGA scanout and F12 backup all reduce
memory traffic compared with the 640x480 version.

Once VGA is ready, the startup page shows a progress gauge for menu buffers,
keyboard, audio, microSD, BIOS scanning, saved settings and joystick startup.
The percentage counts completed initialization stages, not elapsed time or
ROM-loading bytes. Warnings remain visible, and the F12 startup selection
window is unchanged.

Rendering adapts to keep emulation near the normal 50/60 Hz rate without
changing the Z80 clock. Sustained overload is checked every five PAL or six
NTSC frames, so a heavy cartridge should no longer spend several seconds
gradually reducing rendering load. F12 resume keeps the learned rendering
level. This can trade display smoothness for speed; it cannot guarantee full
speed for every ROM. The UART `MSX speed:` lines show the measured emulated
and presented frame rates.

Sprite collisions still run when drawing is skipped, but now use word-sized
masks rather than per-dot loops. Collision timing and game logic are unchanged.
Drawing recovery starts with 10% spare frame time rather than 20%, so games
with a high base CPU cost can recover from a low draw percentage sooner.
For Space Manbow, use **PSG + SCC** audio; FM-PAC is not required by the
original game. Host collision benchmarks are not a guarantee of ESP32 FPS:
compare the UART rates during the same gameplay scene after updating.

Alongside `MSX speed:`, the `MSX work:` line reports sampled milliseconds per
emulated frame for VDP commands, rendering, VGA copying, sprites, audio and
input. `cpu/other` is the remaining frame time, including CPU emulation,
memory accesses and any unsampled work or interruptions; it is not a pure
CPU-cycle measurement. One frame in 17 is sampled to limit timing overhead
and avoid consistently selecting the same frame-skipping phase. Deliberate
pacing waits and time spent in F12 are excluded. Sampled stage timings can
vary, so compare several consecutive lines from the same gameplay scene.

The presentation path reads the cropped core image directly with its row
stride, stages one row in internal memory, expands four pixels into five,
and flushes the VGA cache row immediately. This removes the extra
60 KiB PSRAM staging image and its per-frame copy. The main Z80 interpreter
and byte read/write dispatch routines execute from instruction RAM on
ESP32-S3, without changing the emulated clock. This uses about 32 KiB more
internal instruction memory; the CPU-data allocator still preserves its
existing driver-memory reserve and falls back to PSRAM when needed.

This project keeps the original hardware and software assumptions in mind, but it is still an emulator build on modern hardware. That means the goal is a working, usable system rather than a perfect cycle-accurate reproduction of every board detail.

For setup, build, and firmware update details, read the rest of this folder's documentation and use the project notes in the repository as the main reference.

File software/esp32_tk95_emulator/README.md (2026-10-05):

# ESP32 Microdigital TK95 / TK90X

Standalone TK95 and **48 KiB TK90X** firmware for the shared Retro Hacker
Clone Series ESP32-S3 N16R8 board. The CP400 and MSX firmware folders are
not required to build it. Firmware version: **1.00**.

This is a focused implementation, not a port of all ESPectrum features.
[ESPectrum](https://github.com/EremusOne/ESPectrum) is the reference for
Microdigital frame timing, floating-bus behavior and ROM language selection.
The CPU is the permissively licensed, cycle-stepped
[chips Z80](https://github.com/floooh/chips). No ESPectrum GPL source or
ROM bytes are linked into the firmware. See [dependency provenance](lib/README.md).

## Hardware

The pinout is the same as the CP400 and MSX projects:

| Function | GPIO |
| --- | --- |
| VGA red low/high | 5 / 4 |
| VGA green low/high | 7 / 6 |
| VGA blue low/high | 9 / 8 |
| VGA HSYNC / VSYNC | 2 / 1 |
| Native USB keyboard D- / D+ | 19 / 20 |
| Low-speed USB joystick 1 D- / D+ | 15 / 16 |
| Low-speed USB joystick 2 D- / D+ | 17 / 18 |
| One-bit SD/MMC CMD / CLK / D0 | 38 / 39 / 40 |
| Mono PWM audio | 47 |
| Onboard RGB LED, disabled after VGA setup | 48 |

Use the board's **UART connector** for uploading and diagnostics, not the
native USB keyboard connector. The board must provide USB VBUS. Joysticks
use the existing software low-speed USB transport: not USB hubs, Bluetooth,
or arbitrary full-speed gamepads.

VGA uses the existing 320x240 framebuffer and hardware line doubling.
The 256x192 TK picture is centered with its border, without horizontal
stretching. Select 4:3/aspect mode on a widescreen monitor. The physical VGA
signal stays at the board's standard timing; the selectable emulated
50/60 Hz ULA timing does not reconfigure the monitor.

## Build and upload

From this firmware folder:

```powershell
pio run
make test
make firmware
pio run -t upload
```

`make` automatically finds PlatformIO's usual Windows virtual environment.
`make test` requires native G++ on PATH and PowerShell. PlatformIO is pinned
to `espressif32@6.11.0`, as in the MSX firmware.

`make firmware` builds and verifies `dist\ESP32_TK95-1.00.FLH`: the shared
decimal checksum + `-~` + raw ESP32-S3 application format. First installation
must use UART so the bootloader and dual 4 MiB OTA partition layout are
installed. Subsequent updates use **F12 > Firmware update** and any
compatible `.FLH` package for CP400, MSX, TK95 or Apple II on SD, without
renaming. Prepare the destination emulator's ROMs before switching.
Put packages at the card root so CP400's file picker can also find them.
After restart, use the destination's Firmware update menu to switch again.

The updater validates the package before writing, verifies a second pass,
and selects the inactive OTA slot only after ESP-IDF image verification.
Keep power connected throughout. A filename/checksum is **not a signature**;
only install trusted firmware for this board. The original FLH is preserved.
An older TK updater must first install the current TK package to remove
its filename restriction. Older CP400 layouts need a one-time UART upload
of a current build; FLH cannot change the partition table. Use current
builds for every destination to retain cross-emulator updates.

## SD card and ROMs

Use FAT32. Copy the `sdcard\tk` folder to the card root, alongside `msx`
if you use both firmwares on the same card. Default paths:

```text
tk\
  bios\
    tk95.rom
    tk90.rom
```

Supply legally obtained **raw binary, exactly 16,384-byte ROMs**. No ROMs
are distributed with the project. Git ignores ROM/media files under
`sdcard`. A downloaded HTML page or C header renamed to `.rom` is not a
ROM dump and will not boot.

Either ROM can be selected elsewhere on SD through **F12 > Configuration /
ROM**. The firmware remembers a separate ROM path for each model. It checks
size, not the identity or compatibility of an arbitrary 16 KiB image. TK90X
v1/v2/v3 variants can be supplied as separate files; a selected ROM's custom
extensions are not automatically added as emulated hardware.

The default ROM paths on the card are `/tk/bios/tk95.rom` and
`/tk/bios/tk90.rom`. Move an older root-level `bios` folder under `tk`.
Saved settings from the previous layout automatically migrate the two old
default ROM paths; custom ROM selections, tape paths and other settings
remain unchanged. Save the boot configuration in F12 to persist the migrated
paths. Browsers can still access the whole card; tapes and snapshots may be
organized under `tk` or selected elsewhere.

**ROM language pin** selects the Portuguese/Spanish hardware input used by
the original TK95 and TK90X v1/v2 ROMs. It does not translate the F12 menu
or override the language embedded in a custom ROM. Default: Portuguese.
The default machine is TK95, 60 Hz; only the selected machine's ROM is
required to boot.

Leave the card inserted. F12 can retry an initially failed SD mount.
Restart the board after physically replacing a mounted card.

## F12 menu

F12 is reserved exclusively for the host menu. It pauses CPU, tape and
audio without resetting the machine. Esc moves back one page; F12 resumes
from normal submenus. Destructive confirmations default to cancellation:
press **Y** to confirm or **N/Esc/F12** to cancel.

| Page/action | Available controls |
| --- | --- |
| Configuration / ROM | TK95/TK90X, ROM browser, 50/60 Hz Microdigital ULA, sound, volume, auto boot, render every 1/2/3 frames, ROM language pin |
| Configuration / Media | Save full boot configuration, reboot and save, reboot without saving |
| Media | Attach/play/stop/rewind/eject TAP, load 48K SNA/Z80 snapshots |
| USB joysticks | Per-port Disabled/Kempston/Sinclair 1/Sinclair 2/Cursor, seven-step calibration, live decoded input, clear calibration |
| Warm reset | Reset CPU, retain RAM and running machine configuration, rewind/stop tape |
| Cold boot | Apply selected configuration, clear RAM, start selected ROM, rewind/stop tape |
| Retry microSD | Retry initial mount without disrupting an already mounted card |
| Firmware update | Browse, confirm, validate, install FLH, restart |
| Hardware / help | Hardware summary, key mapping and media instructions |

Arrows navigate. Enter selects. Left/Right changes configuration values.
Browsers traverse folders, use case-insensitive extensions, paginate ten
entries, and support Page Up/Down. Names appear in filesystem order.
Paths longer than 239 bytes or containing unsupported components are
reported and omitted rather than silently truncated.

Model, ROM, ULA timing and ROM language changes are **pending until cold
boot**. Resuming preserves the running machine. Sound, volume, rendering
interval and joystick interfaces apply on resume. Warm reset still uses
the running model, not pending model/ROM selections.

**Save complete boot configuration** saves model, both ROM paths, timing,
language, sound/volume, auto boot, rendering interval, both joystick
interfaces and tape path. It validates the selected boot ROM and tape
before saving. Reboot without saving does not overwrite these defaults.
Joystick calibration is saved separately and immediately in TK-specific
NVS; it does not alter MSX calibration.

Invalid saved settings, missing ROMs/media, malformed files, allocation
failures and SD/NVS errors are reported on screen and UART. Failed media
or snapshot validation retains the previous attachment/machine state.
There is a 2.5-second F12 interception window before automatic boot.

## Keyboard and joysticks

Letters and digits map to the original TK keyboard matrix, not to an
ASCII text injector. Original Spectrum/TK keyword entry therefore applies.
For example, the standard BASIC `LOAD` keyword is on **J**.

| USB key | TK action |
| --- | --- |
| Either Shift | CAPS SHIFT |
| Ctrl / Alt | SYMBOL SHIFT |
| Enter / keypad Enter | ENTER |
| Esc | CAPS SHIFT + SPACE / BREAK |
| Backspace / Delete | CAPS SHIFT + 0 |
| Caps Lock | CAPS SHIFT + 2 |
| Arrows | CAPS SHIFT + 5/6/7/8 |
| F12 | Host menu; never enters the TK matrix |

Common unshifted punctuation keys provide SYMBOL SHIFT combinations.
This is not full PC-layout/localized text entry: use original TK key chords
for symbols that depend on the ROM's keyboard layout.

Calibrate each USB joystick under F12 using neutral, up, right, down, left,
fire A and fire B. Keep the requested control held until the next prompt.
The transport retains the shared board's eight-byte report limit. Select
the matching joystick interface in the game. Standard TK joystick
interfaces expose **one fire button (A)**; B is captured for the shared
calibration model but is not mapped to a second emulated fire button.
Two pads assigned to Kempston merge their inputs; use Sinclair 1/2 for
separate keyboard-mapped players.

## Tape and snapshots

**TAP:** read-only, standard pilot/sync/data pulses, played through the
emulated EAR input at real emulated speed. Blocks require a valid length
and XOR checksum. Images are limited to 4 MiB and staged in RAM; attachment
does not start playback or type a BASIC command.

1. Boot the appropriate ROM and attach a TAP under F12 > Media.
2. Return to BASIC and enter `LOAD ""`.
3. Open F12 > Media, choose **Play tape**, then resume.
4. Use Stop/Rewind to retry. At end of tape, rewind before playing again.

F12 pauses tape position. Rewind and cold/warm reset stop the tape.
Only its path is saved, not tape position. Custom turbo/protected tape
loaders are not certified; TZX, WAV, recording and instant/flash loading
are outside this release.

**Snapshots:** boot the desired TK ROM first, then load from F12 > Media:

- 48K `.sna` (49,179 bytes), restoring PC from the saved RAM stack.
- `.z80` v1, raw or compressed; v2/v3 plain 48K, raw or compressed pages.

128K, SamRam and peripheral-specific snapshot hardware modes are rejected.
Malformed compression, duplicate/missing pages and invalid SNA stacks
are rejected before live RAM/registers change. Snapshots restore the
software state, not a ROM, model, joystick setting or tape position.
Snapshot saving is not implemented.

## Validation and limitations

Host tests exercise synthetic Z80 programs (including indexed/CB operations,
interrupts and ROM write protection), both complete raster sizes, flash
attributes, audio sample budgets, input matrices, TAP pulse counts and EOF,
snapshot formats/rejection, settings, calibration, quiet audio and OTA
failure paths. They contain no commercial ROM data.

The core uses 228 T-states per line, 262/312 lines and a 32-T-state frame
interrupt. Frame targets follow ESPectrum (16,707/19,895 microseconds).
Rendering samples eight-pixel character groups; this release is **not
certified cycle-accurate** for multicolor, snow or other raster-sensitive
demos. Contention and floating-bus support do not imply full ESPectrum
compatibility. AY audio, Betadisk, other machine models, hardware tape
input, mouse and ESPectrum's extended snapshot formats are not included.

Monitor UART `TK speed:` while testing actual games. Rendering every second
or third frame reduces VGA work without changing the emulated CPU clock.
Host tests and a successful ESP32 build do not establish real-board FPS,
electrical behavior or compatibility with every ROM/game.

With your raw ROMs in `sdcard\tk\bios`, run **`make test-roms`** for the
optional, local-only integration tests. They boot each model at both
50 and 60 Hz, enter `PRINT 1+1` through the keyboard matrix, check the
rendered result against that ROM's digit font, and load an original
synthetic BASIC TAP through the ROM's EAR routines. No ROM bytes are
copied into test sources or transmitted elsewhere. These checks passed
with the two user-supplied ROMs during implementation; physical-board
VGA, sound, USB, SD/OTA behavior and game performance remain untested.

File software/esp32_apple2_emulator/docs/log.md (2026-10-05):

# Firmware Change Log

This log tracks user-visible changes to the ESP32 Apple II emulator firmware.
Versions use one major digit and two minor digits, for example 1.00 and 1.01.

## 1.03 - Unreleased

### Changed

- Allowed Firmware update to install compatible CP400, MSX and TK95 FLH packages as well as Apple II packages without renaming, while retaining image, checksum and OTA layout validation.
- Extended firmware-update host tests to install all four emulator packages into mock OTA storage and compare the written payloads.
- Reduced CPU memory-access overhead with precomputed RAM/ROM page mappings and an inlined cycle loop, while retaining the original CPU clock and bank-switch behavior.
- Sent rendered scanlines directly to the VGA framebuffer, removing the intermediate 150 KiB PSRAM framebuffer and its extra copy without reducing resolution.
- Stopped repainting text screens when DOS loaded unrelated graphics memory, while still refreshing modified visible pages and auxiliary display memory.

### Added

- Added checks for all RAM-bank flag combinations, language-card aliases and equivalence between individual CPU ticks and complete frame execution.

### Notes

- On-board measurements of the previous firmware showed about 20.6 ms of CPU work per emulated frame, already above the 16.6 ms budget for 60 fps; the new optimizations still required fresh hardware measurements.

## 1.02 - Unreleased

### Changed

- Moved the 6502 decoder and memory-access hot path into internal instruction RAM to reduce flash-cache overhead during emulation.
- Rendered display rows in internal RAM before copying them to PSRAM and stopped redrawing unchanged screens, while preserving 80-column output, flashing text and display-page changes.
- Avoided calculating unused floating-bus values during keyboard, status and Disk II data-latch reads.

### Added

- Added CPU, video, framebuffer-copy and audio timing to UART diagnostics, alongside redraw counts, the CPU program counter, drive-1 track and elapsed emulated time.
- Added a 512-configuration framebuffer-equivalence regression and checks for display invalidation, including auxiliary memory and flashing text.

### Notes

- Full-speed operation still required new on-board measurements; the previous firmware ran at roughly 20 fps with every-frame rendering and 30.6 fps with every-third-frame rendering on the reported board.

## 1.01 - Unreleased

### Fixed

- Kept Disk II motors running for the hardware's one-second stop delay, so DOS no longer repeated its spin-up wait between sector reads and made booting Karateka appear frozen.

### Added

- Added an optional local Karateka disk regression covering cold boot, `PR#6`, the intro and keyboard-driven entry into the game on both supported machines.

## 1.00 - Unreleased

### Added

- Added standalone Apple II+ and original Apple IIe profiles with 64 KiB and 128 KiB of RAM respectively, using user-supplied machine and Disk II ROMs from the `apple2/bios` SD folder.
- Added full-width 80-column text on the shared VGA board, alongside 40-column text, inverse/flashing characters, lo-res, hi-res, mixed and IIe double-resolution graphics.
- Added native USB keyboard input with control codes, Caps Lock, key repeat and Open/Solid Apple buttons.
- Added two calibrated USB joystick ports mapped to Apple paddles and pushbuttons, and mono speaker audio on GPIO47.
- Added two write-protected slot-6 Disk II drives for 35-track NIB images, with mount and eject actions in F12.
- Added the shared F12 workflow for configuration, saved boot defaults, warm reset, cold boot, SD retry, joystick calibration and firmware updates.
- Added `make firmware` packaging and verification for `ESP32_APPLE2-1.00.FLH`, with Apple-specific filenames and the shared dual-slot OTA layout.
- Added ROM import validation, native regression tests and optional ROM smoke tests covering BASIC, 80-column output and a synthetic NIB boot sector.

### Notes

- Brazilian clone profiles and enhanced IIe/65C02 support were not included in this initial release.
- ROMs and games were not distributed; text used the existing ASCII font rather than a bundled Apple character ROM.
- Disk writes, cassette, snapshots and sector-image formats were not supported.
- Host tests and the ESP32-S3 build were verified, but physical-board operation and real-time speed still required hardware validation.

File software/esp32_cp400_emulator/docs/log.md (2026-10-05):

# Firmware Change Log

This log tracks user-visible changes to the ESP32 CP400 emulator firmware.
Versions use one major digit and two minor digits, for example 1.10 and 1.11.

## 1.13 - Unreleased

### Changed

- Allowed Firmware update to install compatible CP400, MSX, TK95 and Apple II FLH packages without renaming, preserving the source file on SD.
- Replaced reboot-time staging with validated inactive-slot installation, progress and explicit errors before restarting into the selected emulator.
- Paused CPU and software-joystick interrupts during installation and reserved additional menu stack space for buffered OTA updates.
- Adopted the shared dual 4 MiB OTA layout, requiring one UART upload for boards using the older CP400 partition table.
- Added a setup guide and firmware-update host tests covering cross-emulator packages and failure handling.
- Loaded the CP400 BASIC, Extended BASIC, and selected CP400 or CoCo disk controller ROM from `cp400/bios` on the microSD card instead of embedding them in the firmware. Startup now stops with a serial error when a required ROM is missing, unreadable, or the wrong size.
- Drove the sound output on GPIO47 only, matching the board revision that removes the second audio channel. On this module GPIO48 is the data line of the onboard RGB LED, so audio could not share it. The machine's sound is mono, so nothing is lost.
- Raised the audio carrier well above the audible range, so the board's audio filter now removes almost all of it instead of leaving an ultrasonic tone on the jack.
- Moved the emulated ROM and RAM from the external PSRAM chip into the ESP32's internal memory, which is considerably faster for the emulated processor.

### Fixed

- Tracked USB disconnection separately for each joystick connector so activity on one port no longer determined the other port's connection status.
- Removed an empty VGA library manifest so PlatformIO used the existing Arduino library metadata without reporting manifest parsing errors.
- Centered the 256x192 CP400 display area within the active VGA frame in every video mode. Graphics and text modes now share the same origin calculated from the selected VGA resolution instead of using separate manual offsets.
- Turned the onboard RGB LED off at startup. It sits on GPIO48, which the first version of this board also used as a second audio channel, so the sound signal reached the LED as if it were colour data and left it lit. The LED holds the last colour it is given until it is told otherwise, so it is now explicitly cleared when the emulator starts.
- Honoured the sound multiplexer instead of treating it as permanently open, so port writes that were never meant to be audible, such as serial framing and joystick reads, no longer reach the speaker.
- Ignored the two lowest bits of the sound port, which carry the serial and cassette lines rather than sound data and added noise to every sample.
- Stopped the sound output switching once the machine stops producing sound. Holding a level required the output to keep switching, which left a faint carrier on the jack when the machine was silent.

## 1.12 - 2026-08-29

### Changed

- Moved the keyboard port to the ESP32-S3 native USB-OTG host on GPIO19 and GPIO20, so ordinary full speed USB keyboards now work. The previous bit-banged stack could only talk to low speed devices, which is why most keyboards appeared dead or never lit their indicators.
- Requested the HID boot protocol from the keyboard, so keyboards that default to their own report layout still deliver the standard report the emulator expects.
- Turned the native USB serial console off, because the keyboard host and the console cannot share the one USB controller. Serial output and firmware uploads now use the UART port, which already carried the boot log.
- Kept joystick 1 and joystick 2 on the existing bit-banged stack, unchanged.

### Added

- Logged the keyboard's speed, vendor and product IDs, and the interface and endpoint in use, so an unsupported keyboard can be told apart from a power or wiring fault.
- Added `make upload` to build and upload the firmware through the PC USB port configured in `platformio.ini`.
- Added a DELETE action to eject the selected disk image from any of the four drives and persist the empty assignment.

### Fixed

- Removed UART debug writes from the 6809 timer interrupt. They caused an interrupt watchdog reset loop after the USB-OTG keyboard host moved the serial console from native USB CDC to UART0.
- Showed explicit Y/Yes and N/No choices on the firmware installation confirmation screen.
- Waited for ENTER to be released before opening the disk-drive screen, preventing the same key press from immediately opening Drive 0's file picker.

### Notes

- The keyboard connector must be rewired: D- goes to GPIO19 and D+ goes to GPIO20. These pads are tied to the USB PHY inside the chip and cannot be moved to other pins.
- Keyboards containing an internal USB hub are still not supported, because this ESP-IDF version has no hub driver.

## 1.11 - 2026-08-19

### Added

- Added a progress gauge that runs while a firmware update is validated and copied.

### Changed

- Moved the USB keyboard port to GPIO11 and GPIO12, joystick 1 to GPIO15 and GPIO16, and joystick 2 to GPIO17 and GPIO18, to simplify cable routing on the board.
- Gave every F12 screen the same layout, with the product name and screen title in the header, matching separator lines, and key hints in the footer. The disk image picker, firmware update screens, and error messages previously used their own styles.
- Renamed the "Joystick calibration" menu entry to "Joystick setup".
- Turned the joystick Serial debug output off by default.
- Listed only files with a matching extension when choosing a firmware or disk image, hiding folders such as System Volume Information that could not be opened anyway.

## 1.10 - 2026-08-18

### Added

- Added independent joystick 1 and joystick 2 control mapping from the F12 menu.
- Added guided capture for joystick neutral, up, down, left, right, button 1, and button 2 states.
- Added persistent raw HID joystick mappings to support controllers with different report layouts.
- Added a Serial joystick debug mode in the F12 menu that logs raw USB reports, decoded controls, and stored mappings at 115200 baud.
- Added a Makefile workflow that builds, packages, and verifies `.FLH` firmware updates for the F12 menu.
- Added firmware version control through the Makefile and versioned update-package filenames.

### Fixed

- Stored the PIA control registers at $FF01 and $FF03 on write, so the joystick multiplexer select bits change as the machine requests. They were never updated, which froze the multiplexer on a single channel and made every axis read return the same value.
- Restored the CP400 PIA joystick multiplexer order, which had been changed incorrectly and routed joystick 1's horizontal axis to the vertical channel while the horizontal channel read the unused second joystick.
- Centred the default joystick axis values, so a disconnected or silent joystick no longer reads as held fully left and up.
- Prevented an empty comparison mask from matching every direction at once, which cancelled horizontal and vertical movement and left the pointer centred.
- Moved joystick tracing to a dedicated task on the free core, so the video task cannot starve it and Serial output cannot disturb the bit-banged USB timing.
- Routed joystick tracing to the UART0 console used by the rest of the boot output, instead of the separate native USB serial port where it was invisible.
- Mirrored a single connected joystick's axes onto both CP400 joystick channels, so games work regardless of which joystick they read or which USB port the controller uses.
- Logged USB device enumeration with port number and vendor/product IDs, and the stored joystick mappings at boot.
- Replaced whole-report comparison with per-control bit masks so hat switches, buttons, and analog axes are matched independently.
- Excluded report bytes that change while the joystick is at rest, so counters and noisy axes no longer block button detection.
- Mapped either physical joystick button to the CP400's single fire input for that joystick.
- Added automatic detection of the standard Windows PlatformIO CLI installation.
- Corrected `.FLH` package checksums to match the F12 firmware validator.
- Fixed F12 firmware staging so stale or partial update files are replaced and verified before rebooting.

## 1.00 - 2026-08-17

### Added

- First tracked firmware release for the ESP32 CP400 emulator.
- Added CP400/CoCo 2 emulation with VGA output, USB keyboard and joystick input, SD-backed disk images, the F12 system menu, and SD-card firmware updates.

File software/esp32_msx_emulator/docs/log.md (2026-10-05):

# Firmware Change Log

This log tracks user-visible changes to the ESP32 MSX / fMSX firmware.
Versions use one major digit and two minor digits, for example 1.00 and 1.01.

## 1.01 - 2026-09-13

### Added

- Added per-slot detected mapper/source displays and manual mapper overrides in Media, with Auto reset and saved-configuration migration.
- Added a machine-wide audio profile under Media, including FM-PAC/MSX-MUSIC and combined SCC/FM operation, with a shared user-supplied audio BIOS on microSD.
- Embedded PicoVerse's 3115-entry SHA-1 mapper database, translated its supported mapper IDs for fMSX, and reported the selected banked mapper on UART.
- Added disk images for drives A and B and read-only CAS tape attachment through F12, with ejection and tape rewind.
- Applied successful disk and tape changes to the running machine without a cold reset and included their paths in saved boot defaults while preserving older settings.
- Added optional user-supplied disk BIOS import for all profiles, using a separate disk slot that preserved Omega and Panasonic startup and Kanji ROMs.

### Changed

- Allowed Firmware update to install compatible CP400, TK95 and Apple II FLH packages as well as MSX packages without renaming, while retaining image, checksum and OTA layout validation.
- Extended firmware-update host tests to install all four emulator packages into mock OTA storage and compare the written payloads.
- Removed the extra PSRAM frame copy, scaled each VGA row in internal memory and wrote back its cache immediately to reduce frame-presentation overhead without changing the picture.
- Moved the main Z80 interpreter and memory read/write dispatch into ESP32-S3 instruction RAM while retaining the existing driver-memory reserve.
- Reduced ordinary Z80 memory-access overhead by bypassing peripheral-state checks for normal reads and mapped-RAM writes.
- Added sampled UART timing for CPU/other work, VDP commands, rendering, VGA copying, sprites, audio and input so persistent game slowdowns could be diagnosed on the board.
- Reduced sprite-collision overhead on every emulated scanline using word-sized masks while preserving clipping, magnification and beam-timed status reads.
- Allowed drawing to recover with 10% spare frame time instead of requiring 20%, helping CPU-heavy games recover from low presentation rates after a busy scene.
- Restored 320x240 VGA timing and the lightweight core renderer after the 640x480 version slowed games, while retaining full-width picture scaling instead of extra side bars.
- Enabled saving directly to attached DSK files on microSD from Disk BASIC and supported controller writes, synchronizing each sector before reporting success.
- Reported disk write failures to the emulated software and UART, required reattachment after a storage write fault, and rejected mounting the same writable image in both drives.
- Presented cartridge slots, mapper controls, disk drives, tape selection and rewind directly on F12's Media page, with only Audio opening a configuration submenu.
- Added Media-page options to reboot with or without saving the complete boot configuration, and prevented rebooting when validation or saving failed.
- Allowed F12 to resume directly from Media pages without rebooting for disk and tape changes, while cartridge changes remained pending until a cold boot.
- Made the MSX firmware independently buildable by including local copies of its board definition, VGA, graphics, BusIO and USB transport dependencies instead of reading files from the CP400 firmware.
- Made the joystick timing and packet tests use the local USB transport headers so the tests also ran without the CP400 project.

### Fixed

- Reworked disk attachment to use bounded buffered reads through aligned internal memory with task yields, instead of one unbuffered image read into PSRAM, and reported the failing stage, byte offset and OS error when SD access failed.
- Corrected Tiny Magic 1.1's automatic mapper selection from plain Konami to Konami SCC using its exact ROM fingerprint, while preserving explicit overrides and the fallback for unknown images.
- Reported known unsupported mapper hardware instead of guessing an incompatible mapper.

## 1.00 - 2026-09-10

### Added

- Added Panasonic FS-A1WSX, FS-A1F and FS-A1FX BIOS profiles with 64 KiB RAM defaults and local import of BIOS, sub-ROM, Kanji BASIC and Kanji font components into one ROM file per profile.

- Added independent low-speed USB gamepad input on the two joystick connectors, mapped directions and two fire buttons to MSX joystick ports 1 and 2, and released input when a pad disconnected.
- Added an F12 joystick calibration wizard and live input display, saved each port's calibration by USB device identity, and kept uncalibrated or incompatible reports neutral.

- Added an independent, non-commercial fMSX-based MSX1/MSX2/MSX2+ firmware for the shared ESP32-S3 N16R8 board.
- Matched the existing board's VGA, native USB keyboard, one-bit SD/MMC, and GPIO47 mono audio wiring, and reserved GPIO48 for the onboard LED.
- Added an F12 configuration menu that paused and resumed emulation, selected BIOS profiles and RAM sizes, controlled sound and automatic boot, saved boot defaults, and cold-booted another selected ROM.
- Added active-low MSX keyboard input from a directly connected USB boot keyboard, reserved F12 for configuration, rejected rollover reports, and released held keys on disconnect.
- Added initial Omega MSX2+ NTSC, Gradiente Expert 1.1, and Sharp Hotbit 1.2 BIOS profiles with SD-card ROM loading and explicit errors for missing or malformed files.
- Added a local ROM importer that selected either 256 KiB Omega bank, defaulted to the first bank, preserved the selected bank as one complete ROM, and generated copy-verification checksums without embedding ROMs in firmware.
- Added custom MSX1, MSX2, and MSX2+ boot profiles discoverable from SD without rebuilding firmware.
- Added independent PlatformIO and make build targets and ROM-import regression checks.
- Added CP400-compatible FLH packaging in the dist folder through `make` and `make firmware`, with checksum and payload verification, and removed the selected package through `make clean`.
- Added SD-card cartridge ROM selection and ejection for emulated slots 1 and 2, applied the selected cartridges on cold boot, and saved both assignments with the boot defaults while preserving older settings.
- Added a paginated folder browser for cartridge ROMs and firmware packages, with case-insensitive extension matching and explicit errors for invalid paths or files.
- Added an F12 firmware-update flow with confirmation, progress, FLH validation, inactive-partition installation, and automatic reboot after success.

### Changed

- Replaced the startup screen's USB keyboard pin text with a progress gauge and named initialization stages, retaining the F12 prompt and visible startup warnings.
- Hid the Windows-created System Volume Information folder from cartridge and firmware microSD browsers without deleting it or affecting pagination.
- Redrew the joystick diagnostic screen only when displayed values or menu selection changed, instead of repeatedly flushing an unchanged VGA frame.
- Reduced joystick calibration to neutral, four cardinal directions and two fire buttons, deriving diagonals without asking the user to capture them.
- Preferred internal SRAM for small CPU RAM, BIOS and cartridge allocations while reserving memory for board drivers, and retained PSRAM for large allocations.
- Adapted the percentage of rendered frames to available processing time while keeping the normal emulated Z80 clock, input polling, and sound cadence.
- Reported emulated and displayed frame rates on UART to make real-board speed measurable.
- Paused the software joystick host while saving settings or installing firmware, then restarted device detection before accepting fresh input.

- Placed F12 options on consecutive text rows without blank lines between them.

### Fixed

- Reduced the slow-start rendering ramp by reacting to sustained overload every five PAL or six NTSC frames instead of waiting for repeated half-second adjustments.
- Retained the learned rendering level when resuming from F12 while resetting elapsed-time debt, avoiding another speed ramp after menu use.
- Corrected the original MSX2+ startup animation's beam-timed sprite collisions and SCREEN 6 coarse/fine scrolling, page wrapping and edge masking so the logo moved progressively instead of appearing abruptly.
- Corrected SCREEN 6 sprite color-pair sampling, removing a spurious colored bar from the startup logo.

- Kept Omega's BIOS, BASIC, extension and startup code in one 256 KiB ROM file and mapped the previously omitted Kanji BASIC region containing the original MSX logo, without using either cartridge slot.
- Emulated the MSX2+ reset-status register and visible-scanline sprite-collision polling so the original startup animation could finish and proceed to BASIC.
- Made F12 mute and Sound Off fade GPIO47 to a steady low output and stop its sample timer, rather than continuing a 50% PWM carrier.
- Faded sustained silent audio to a non-switching GPIO47 output, stopped its sample timer when drained, and restarted playback only for new sound.
- Held the last audio sample on buffer underrun instead of abruptly switching to midscale, and ramped playback transitions to reduce clicks.
- Started USB reply decoding at the first K transition so idle-J gaps no longer corrupted ACK synchronization and prevented joystick enumeration.
- Acknowledged validated USB DATA retransmissions promptly, preventing gamepads from repeatedly returning the initial neutral report instead of new control values.
- Allowed joystick reports to settle before capture, learned noise only at neutral, and displayed and logged calibration failures or successful saves explicitly.
- Kept USB receive sampling in internal instruction RAM, bounded its edge buffer, and used CPU-cycle inactivity deadlines instead of compiler-dependent loop counts.
- Allowed at least 10 ms of joystick recovery after USB reset and logged failed descriptor exchanges with packet results and captured-edge counts.
- Paced every emulated frame independently of display updates and avoided an unconditional RTOS sleep on every drawn frame when already running behind.
- Replaced USB NOP-delay calibration with absolute CPU-cycle transmission timing in internal instruction RAM, removing the calibration failure that left the joystick host unavailable.
- Released the USB lines after the end-of-packet J bit instead of holding additional idle bits while a joystick could already be replying.
- Added USB enumeration progress diagnostics and stopped logging missing calibration records as errors on first use.

- Eliminated repeated Library Manager manifest parsing errors when building with the shared VGA library.

### Know issues with this version

- Audio quality is not good, especially at higher sample rates.
- The emulator is a bit slow when compared to the real Z-80
- The firmware does not yet support all MSX hardware features, such as disk drives.

### Notes

- Limited the Panasonic profiles to BIOS/BASIC, startup, cartridge and Kanji support; built-in applications, disk hardware and Panasonic turbo/firmware-mapper features were not included.

- Required user-supplied BIOS images and retained the original fMSX author's non-commercial terms and attribution.
- Used fMSX's generic machine models rather than emulating the physical Omega board's optional flash, disk, and expansion hardware.
- Required directly connected low-speed HID gamepads with learnable reports of at most eight bytes; full-speed controllers and USB hubs were not supported on the joystick ports.
- Left disk and tape browsing and save states outside the initial release.

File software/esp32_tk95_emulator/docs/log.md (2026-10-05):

# Firmware Change Log

This log tracks user-visible changes to the ESP32 TK95 / TK90X firmware.
Versions use one major digit and two minor digits, for example 1.00 and 1.01.

## 1.00 - Unreleased

### Added

- Added TK95 and 48 KiB TK90X emulation on the shared ESP32-S3 N16R8 CP400/MSX hardware.
- Added an F12 menu for ROM and machine selection, 50/60 Hz Microdigital timing, Portuguese/Spanish ROM selection, sound, volume, rendering interval and automatic boot.
- Added SD-loaded 16 KiB ROMs, standard TAP playback and 48K SNA/Z80 snapshot loading without embedding ROM data.
- Added dual USB joystick calibration, live input display and Kempston, Sinclair 1/2 and Cursor interface choices.
- Added separate TK boot defaults and joystick calibration storage, cold boot with or without saving, and warm reset with retained RAM.
- Added validated SD firmware updates, standalone build dependencies, native regression tests and the verified ESP32_TK95-1.00.FLH build package.

### Changed

- Allowed Firmware update to install compatible CP400, MSX and Apple II FLH packages as well as TK95 packages without renaming, while retaining image, checksum and OTA layout validation.
- Extended firmware-update host tests to install all four emulator packages into mock OTA storage and compare the written payloads.
- Moved the default SD ROM layout under the tk folder so TK and MSX files could share a card without mixing their BIOS directories.
- Migrated saved default ROM paths to the new TK layout while preserving custom ROM selections, tape paths and other settings.
- Changed keyboard and joystick UART diagnostic labels to identify the TK firmware instead of MSX.
- Updated firmware-update regression checks to validate generated TK firmware packages.

### Notes

- Limited the initial release to beeper audio, read-only standard TAP playback and loading plain 48K snapshots.
- Left AY, Betadisk, TZX, tape recording, snapshot saving and cycle-accuracy certification outside the initial release.

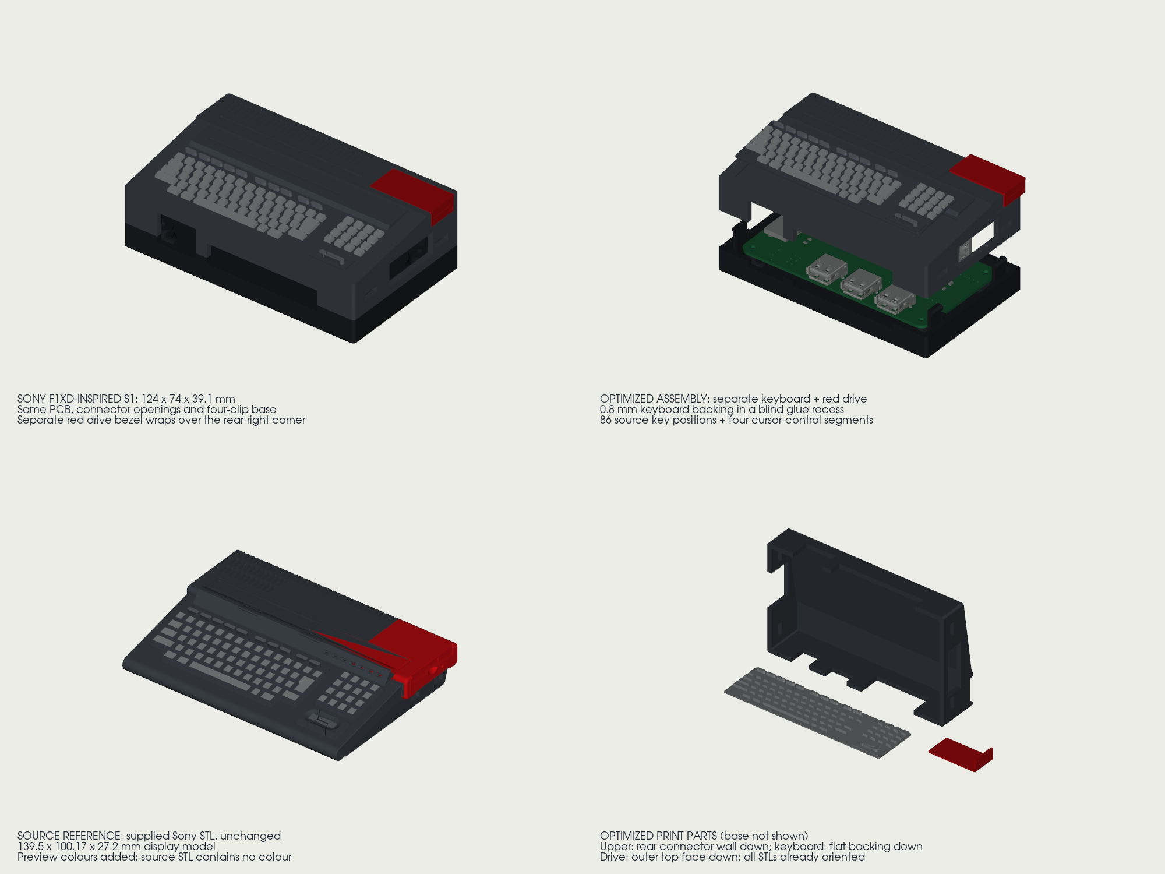
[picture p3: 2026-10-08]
hardware/cases/sony/preview.png

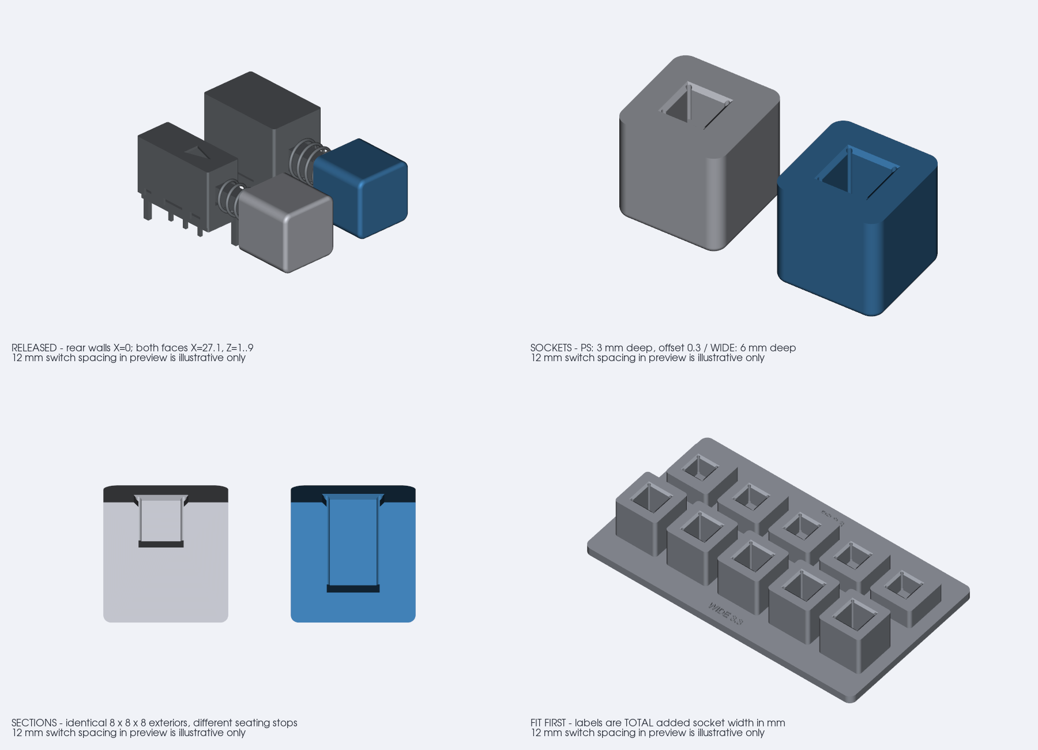
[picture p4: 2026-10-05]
hardware/cases/caps/caps_preview.png

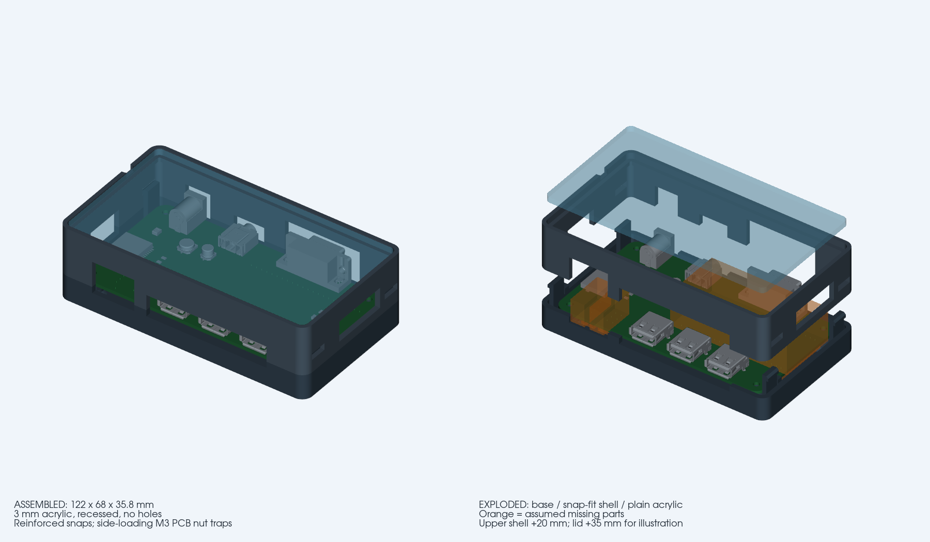
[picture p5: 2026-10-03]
hardware/cases/standard/preview.png

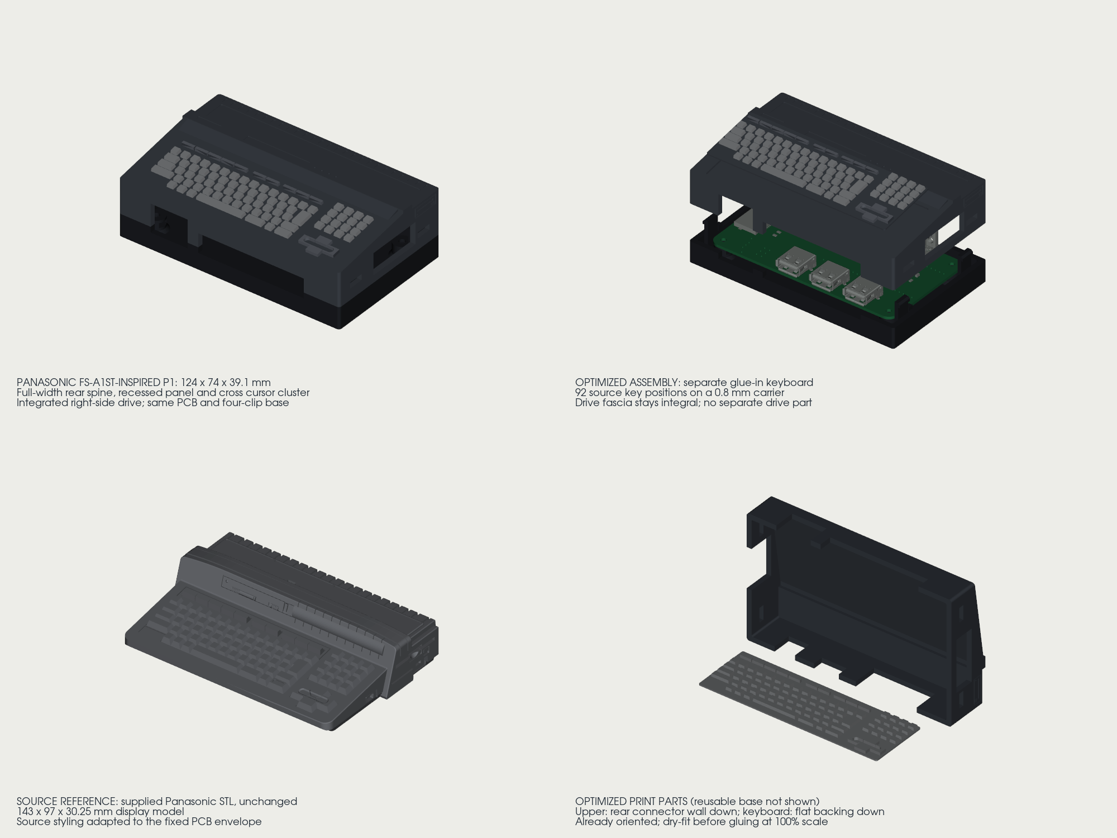
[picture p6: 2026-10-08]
hardware/cases/panasonic/preview.png

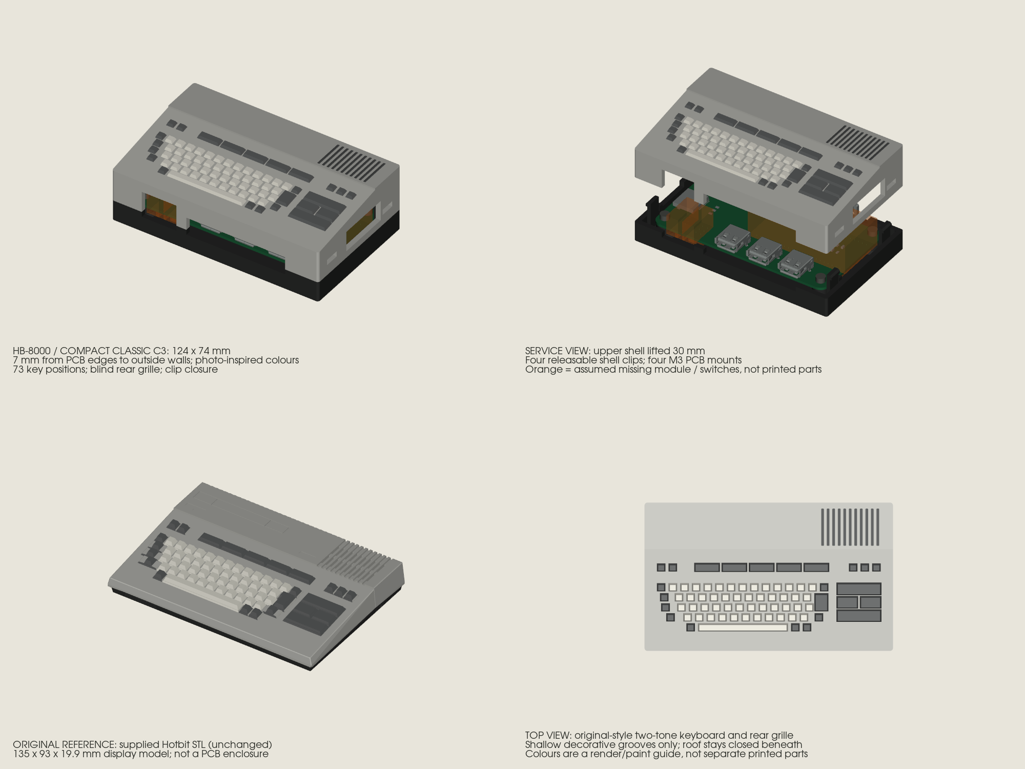
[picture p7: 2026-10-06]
hardware/cases/hb-8000/classic_preview.png

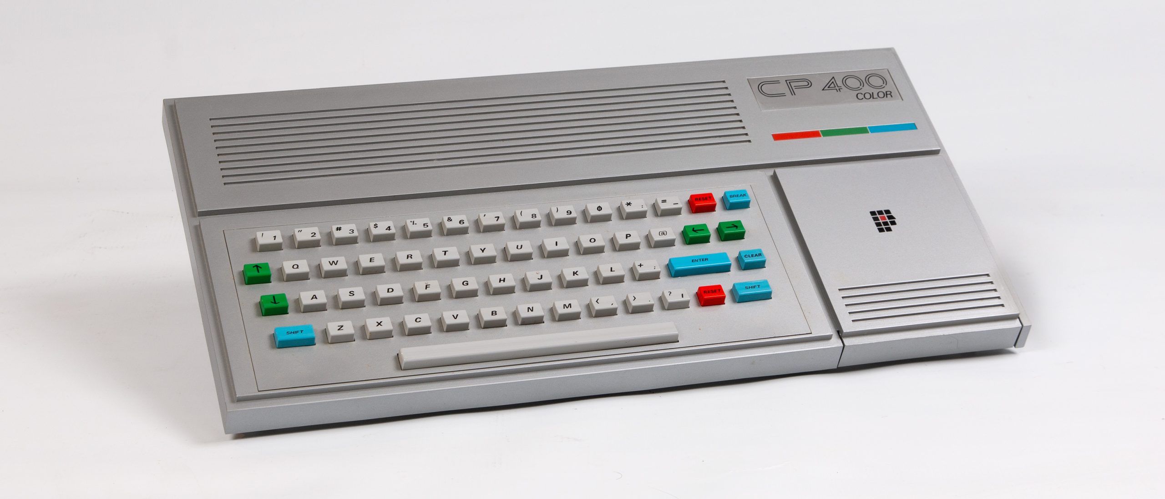
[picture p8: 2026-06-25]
images/cp400.jpg

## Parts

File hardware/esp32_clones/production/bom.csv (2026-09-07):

Designator | Footprint | Quantity | Value | LCSC Part #
C1 | CP_Elec_6.3x3 | 1 | 220UF
C2 | CP_Elec_5x4.5 | 1 | 10UF
C4 | 0805 | 1 | 100NF
C6 | 0805 | 1 | 47NF
F1 | 1210 | 1 | Fuse
J1 | BarrelJack_Horizontal | 1 | Barrel_Jack
J2 | Conn_uSDcard | 1 | Micro_SD_Card
J3 | PJ-307 | 1 | AudioJack2_Ground
J4 | PS-12E05 | 1 | ~
J5 | PS-22F05 | 1 | ~
J6, J7, J8 | TE_6364372-2 | 3 | USB_A
J9 | DSUB-15-HD_Socket_Horizontal_P2.29x1.90mm_EdgePinOffset3.03mm_Housed_MountingHolesOffset4.94mm | 1 | DA15_Pins
R1, R4, R7 | 0805 | 3 | 10K
R10, R12, R8 | 0805 | 3 | 1.2K
R11, R13, R9 | 0805 | 3 | 560
R2, R5 | 0805 | 2 | 330
U1 | ESP32-S3-WROOM-1 | 1 | ~

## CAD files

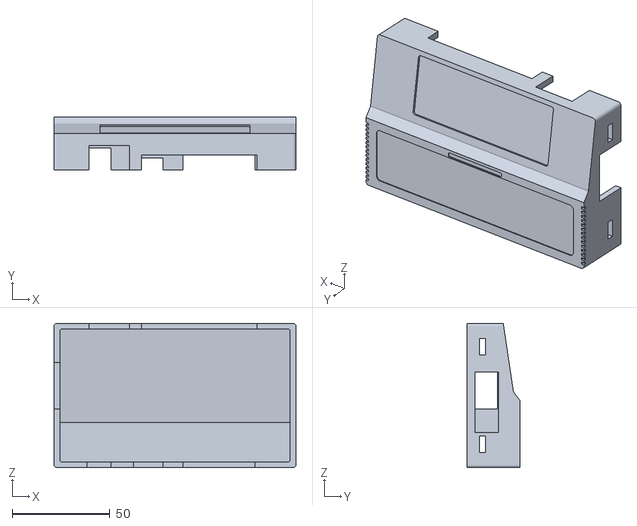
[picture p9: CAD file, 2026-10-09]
hardware/cases/apple2/apple2_upper_optimized.stl
124.0 x 27.0 x 74.0

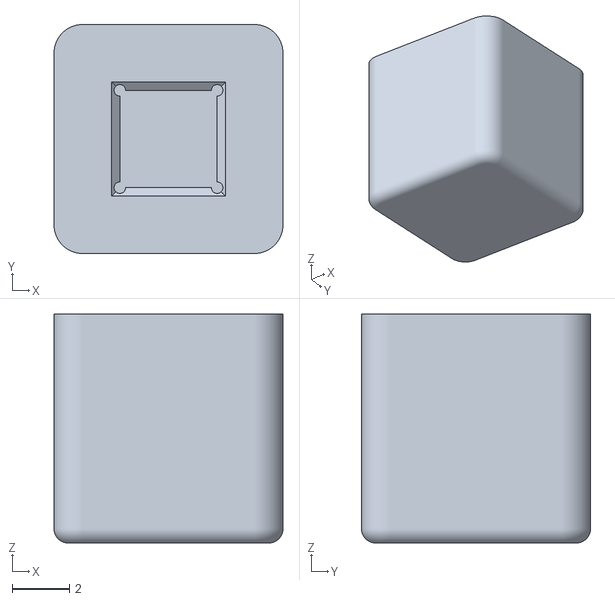
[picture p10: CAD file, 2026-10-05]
hardware/cases/caps/pushbutton_12_2x7_7_cap.stl
8.00 x 8.00 x 8.00

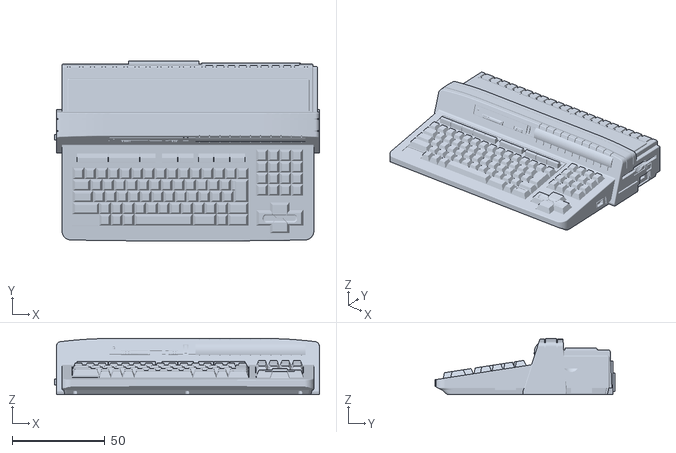
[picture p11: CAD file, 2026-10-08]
hardware/cases/panasonic/FS-A1ST_1_3_scale.stl
143.0 x 97.0 x 30.2

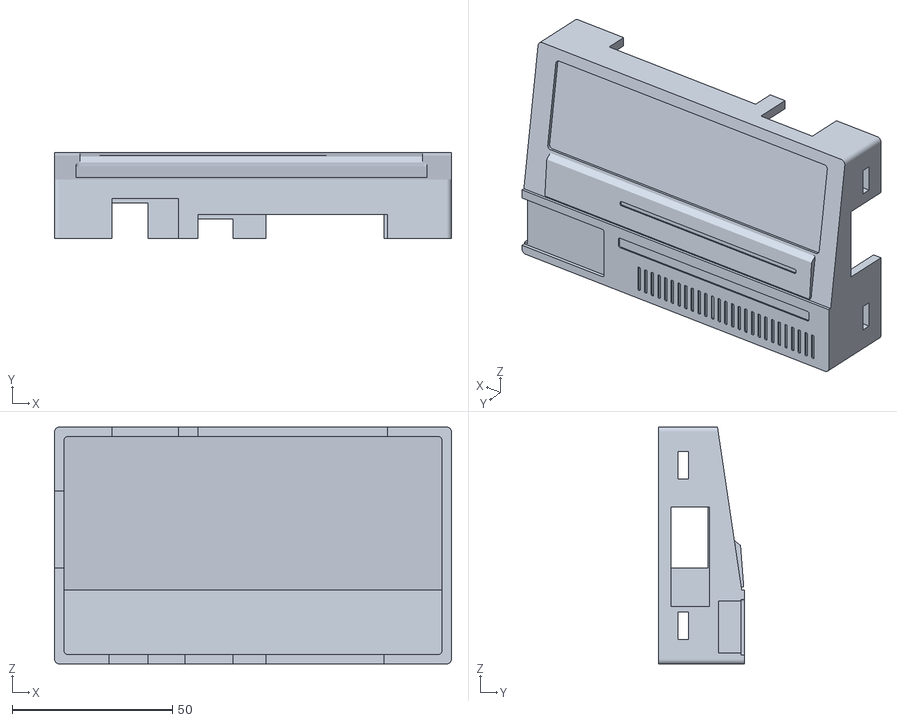
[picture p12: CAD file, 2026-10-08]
hardware/cases/sony/f1xd_upper_optimized.stl
124.0 x 27.0 x 74.0

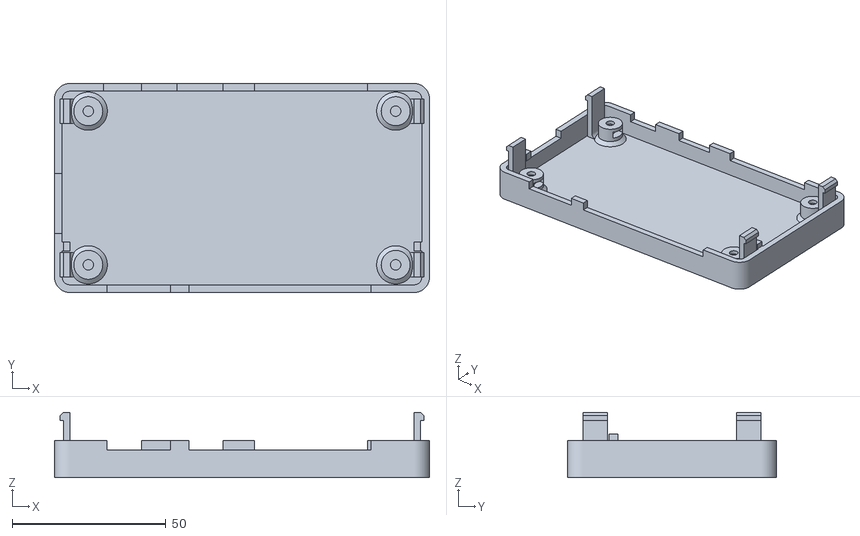
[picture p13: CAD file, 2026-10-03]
hardware/cases/standard/base.stl
122.0 x 68.0 x 21.2

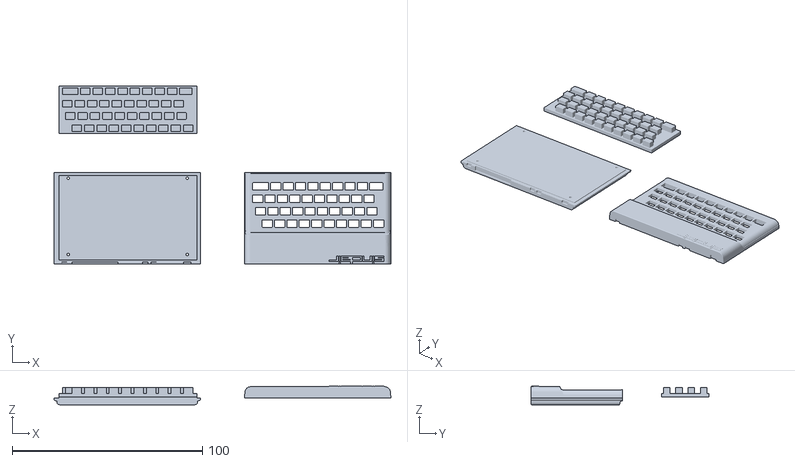
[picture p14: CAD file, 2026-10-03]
hardware/cases/zx/ZXSpectrum_1_3_scale_open.stl
177.0 x 93.5 x 9.75

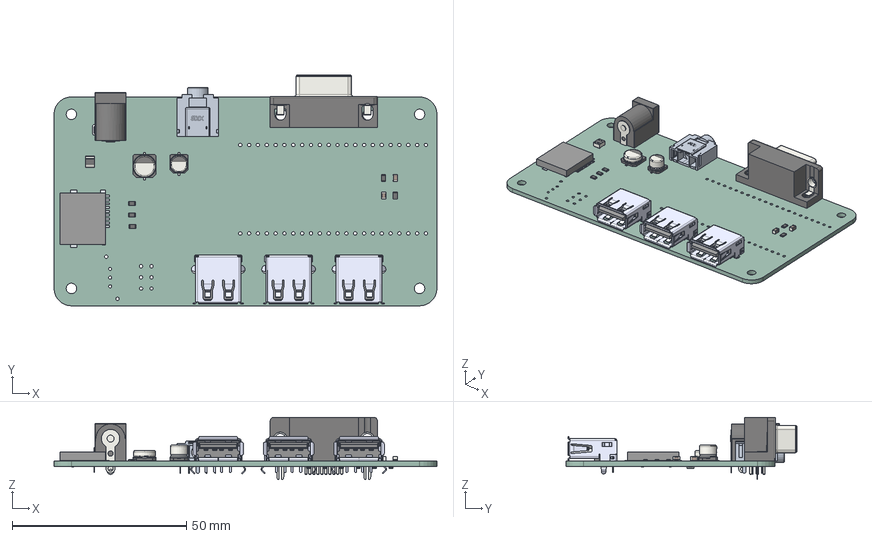
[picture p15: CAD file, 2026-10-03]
hardware/esp32_clones/esp32_clones.step
110.0 x 66.2 x 17.9 mm
Pins
Lugs
C_0805_2012Metric x 2
CP_Elec_5x45
R_0805_2012Metric x 11
BarrelJack_Horizontal
Fuse_1210_3225Metric
PJ-307-HD-X
USB-A1HSW6 x 3
CP_Elec_63x3
DSUB-15-HD_Socket_Horizontal_P2.29x1.90mm_EdgePinOffset3.03mm_Housed_ MountingHolesOffset4.94mm
esp32_clones_PCB

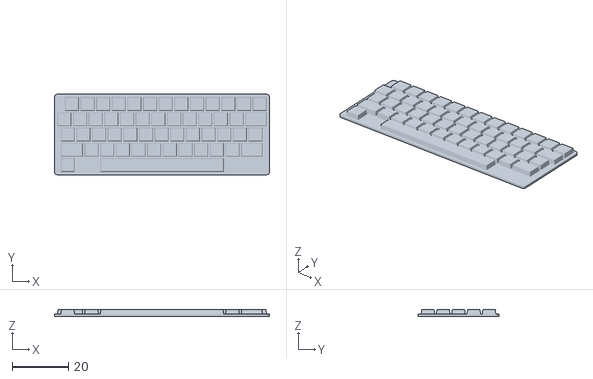
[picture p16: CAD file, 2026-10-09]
hardware/cases/apple2/apple2_keyboard_optimized.stl
76.4 x 28.6 x 2.45

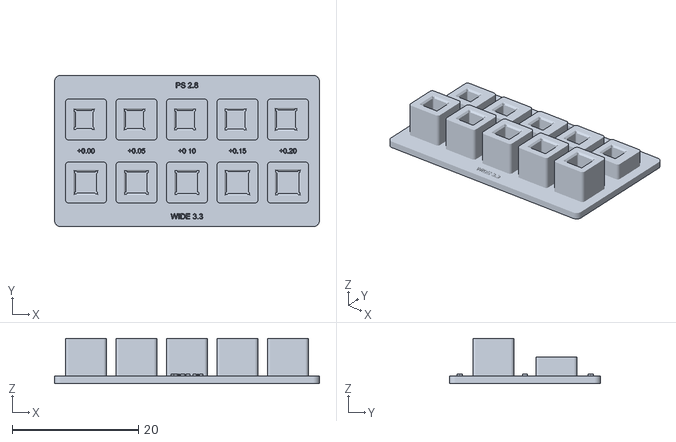
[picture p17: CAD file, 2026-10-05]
hardware/cases/caps/socket_fit_samples.stl
42.0 x 24.0 x 7.20

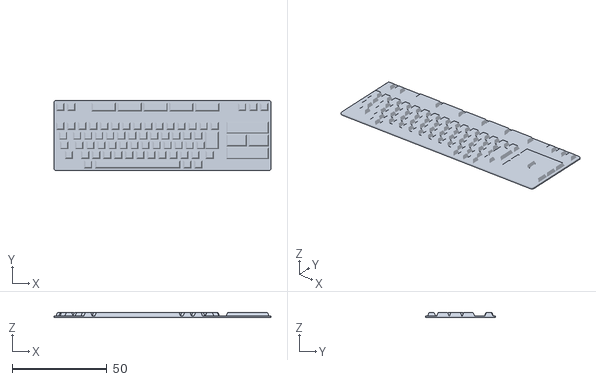
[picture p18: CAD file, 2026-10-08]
hardware/cases/hb-8000/classic_keyboard_optimized.stl
114.2 x 36.8 x 2.45

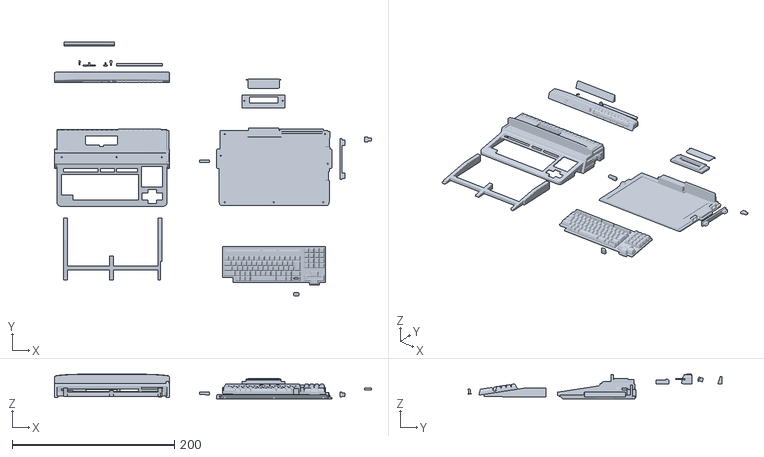
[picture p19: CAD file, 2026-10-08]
hardware/cases/panasonic/FS-A1ST_1_3_scale_open.stl
391.0 x 313.0 x 30.2

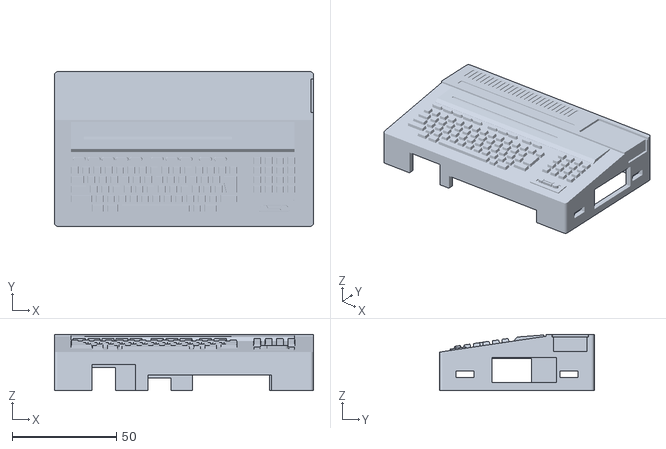
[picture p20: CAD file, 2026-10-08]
hardware/cases/sony/f1xd_upper.stl
124.0 x 74.0 x 27.0

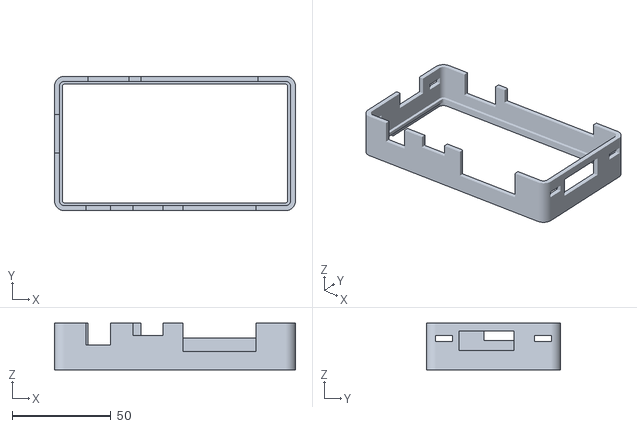
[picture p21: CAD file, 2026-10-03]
hardware/cases/standard/upper_shell.stl
122.0 x 68.0 x 23.7

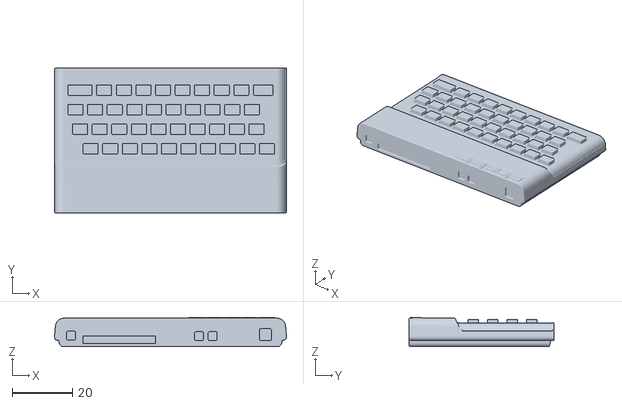
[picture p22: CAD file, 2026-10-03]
hardware/cases/zx/ZXSpectrum_1_3_scale.stl
77.0 x 48.0 x 9.75

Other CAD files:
hardware/cases/hb-8000/classic_upper_optimized.stl
hardware/cases/apple2/apple2_upper.stl
hardware/cases/caps/PS-12E05_cap.stl
hardware/cases/hb-8000/classic_upper.stl
hardware/cases/apple2/APPLE2_1_3_scale.stl
hardware/cases/apple2/APPLE2_1_3_scale_open.stl
hardware/cases/apple2/APPLE2_1_3_scale_open2.stl
hardware/cases/apple2/apple2_base.stl
hardware/cases/hb-8000/HB-8000_1_3_scale.stl
hardware/cases/hb-8000/HB-8000_1_3_scale_open.stl
hardware/cases/hb-8000/wasteland_base.stl
hardware/cases/hb-8000/wasteland_upper.stl
hardware/cases/panasonic/a1st_keyboard_optimized.stl
hardware/cases/panasonic/a1st_upper.stl
hardware/cases/panasonic/a1st_upper_optimized.stl
hardware/cases/sony/HB-F1XD_1_3_scale.stl
hardware/cases/sony/HB-F1XD_1_3_scale_open.stl
hardware/cases/sony/f1xd_drive_red.stl
hardware/cases/sony/f1xd_keyboard_optimized.stl
hardware/cases/standard/lid.stl
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

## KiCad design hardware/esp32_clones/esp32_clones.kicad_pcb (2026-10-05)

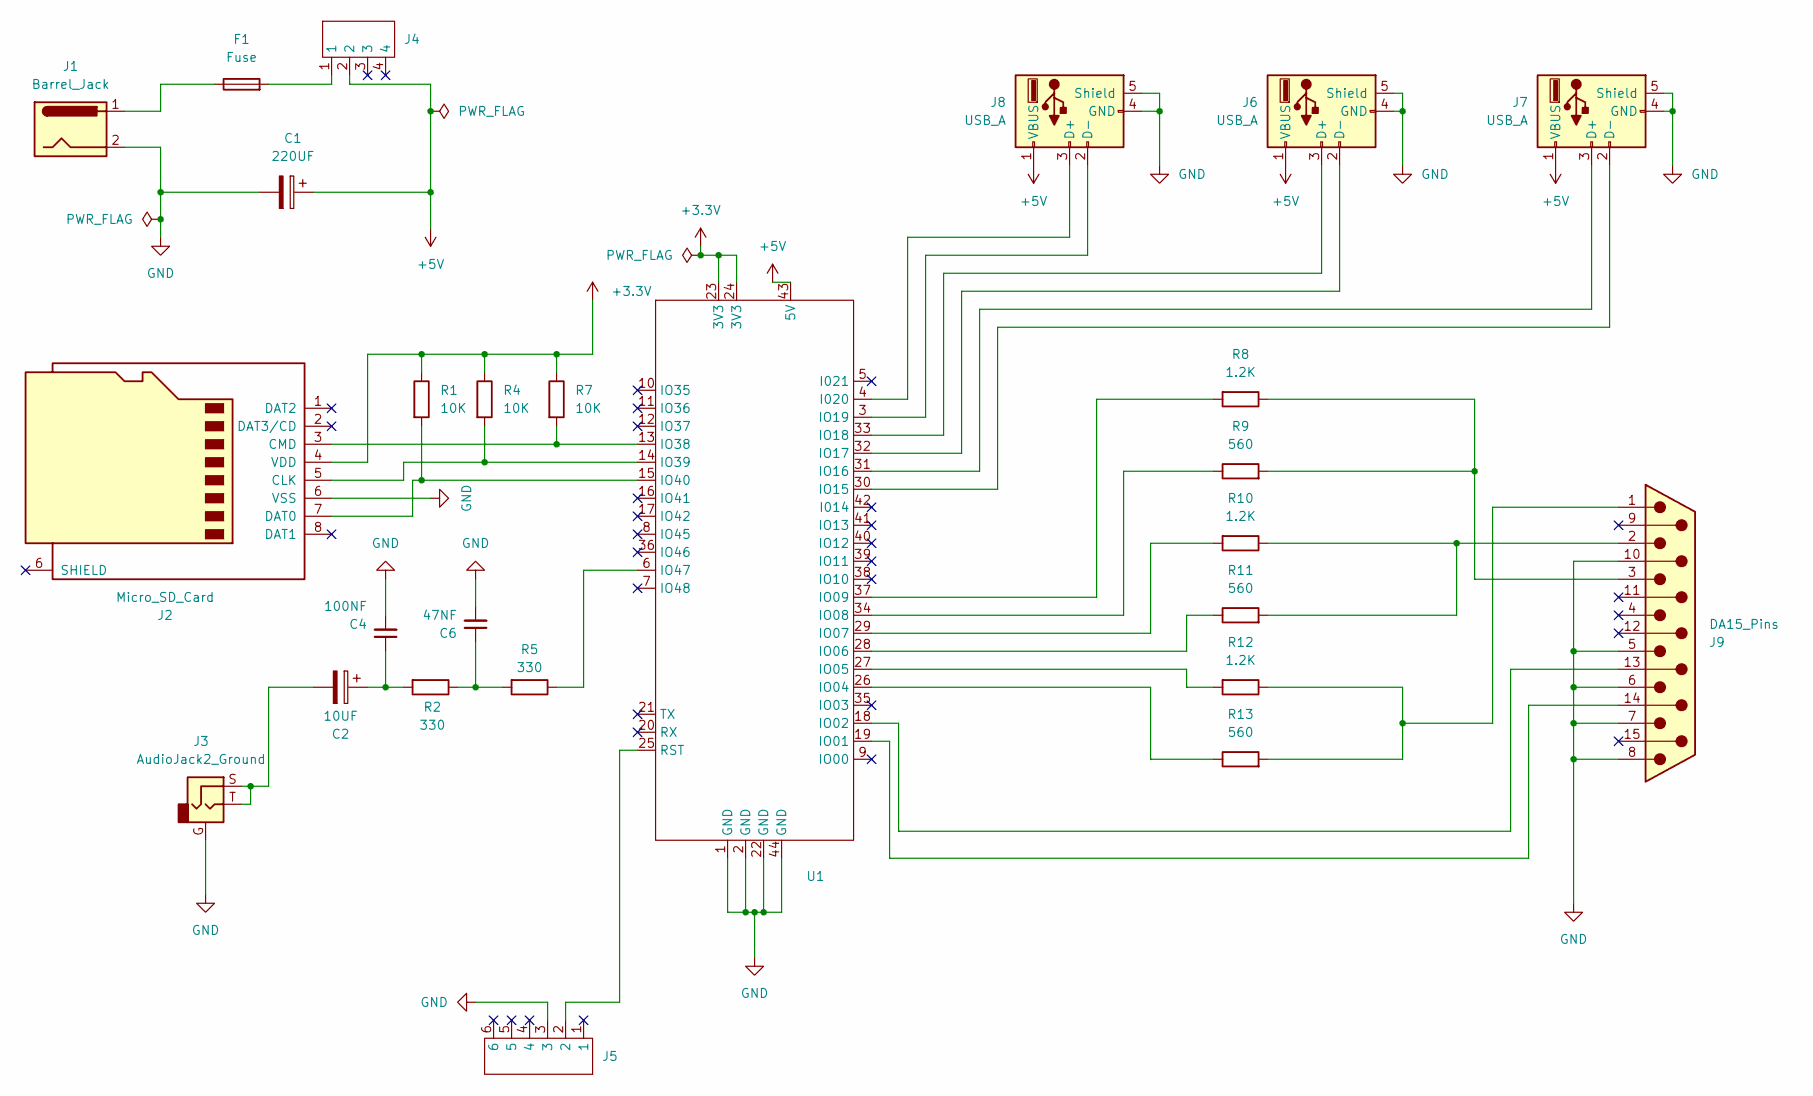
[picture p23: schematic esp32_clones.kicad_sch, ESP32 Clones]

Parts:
C1: 220UF; CP_Elec_6.3x3
C2: 10UF; CP_Elec_5x4.5
C4: 100NF; C_0805_2012Metric_Pad1.18x1.45mm_HandSolder
C6: 47NF; C_0805_2012Metric_Pad1.18x1.45mm_HandSolder
F1: Fuse; Fuse_1210_3225Metric
J1: Barrel_Jack; BarrelJack_Horizontal
J2: Micro_SD_Card; Conn_uSDcard
J3: AudioJack2_Ground; PJ-307
J4: PS-12E05
J5: PS-22F05
J6, J7, J8: USB_A; TE_6364372-2
J9: DA15_Pins; DSUB-15-HD_Socket_Horizontal_P2.29x1.90mm_EdgePinOffset3.03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
R1, R4, R7: 10K; R_0805_2012Metric_Pad1.20x1.40mm_HandSolder
R2, R5: 330; R_0805_2012Metric_Pad1.20x1.40mm_HandSolder
R8, R10, R12: 1.2K; R_0805_2012Metric_Pad1.20x1.40mm_HandSolder
R9, R11, R13: 560; R_0805_2012Metric_Pad1.20x1.40mm_HandSolder
U1: ESP32-S3-WROOM-1

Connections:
+3.3V: J2.4 (VDD), R1.1, R4.1, R7.1, U1.23 (3V3), U1.24 (3V3)
+5V: C1.1, J4.2, J6.1 (VBUS), J7.1 (VBUS), J8.1 (VBUS), U1.43 (5V)
GND: C1.2, C4.2, C6.2, J1.2, J2.6 (VSS), J3.G, J5.3, J6.4 (GND), J6.5 (Shield), J7.4 (GND), J7.5 (Shield), J8.4 (GND), J8.5 (Shield), J9.5, J9.6, J9.7, J9.8, J9.10, U1.1 (GND), U1.2 (GND), U1.22 (GND), U1.44 (GND)
unnamed: C2.1, C4.1, R2.2
unnamed: C2.2, J3.S, J3.T
unnamed: C6.1, R2.1, R5.2
unnamed: F1.1, J1.1
unnamed: F1.2, J4.1
unnamed: J2.5 (CLK), R4.2, U1.14 (IO39)
unnamed: J2.3 (CMD), R7.2, U1.13 (IO38)
unnamed: J2.7 (DAT0), R1.2, U1.15 (IO40)
unnamed: J6.3 (D+), U1.33 (IO18)
unnamed: J6.2 (D-), U1.32 (IO17)
unnamed: J7.3 (D+), U1.31 (IO16)
unnamed: J7.2 (D-), U1.30 (IO15)
unnamed: J8.3 (D+), U1.4 (I020)
unnamed: J8.2 (D-), U1.3 (IO19)
unnamed: J9.13, U1.18 (IO02)
unnamed: J9.14, U1.19 (IO01)
unnamed: J9.1, R12.1, R13.2
unnamed: J9.2, R10.1, R11.2
unnamed: J9.3, R8.1, R9.2
unnamed: R13.1, U1.26 (IO04)
unnamed: R12.2, U1.27 (IO05)
unnamed: R11.1, U1.28 (IO06)
unnamed: R10.2, U1.29 (IO07)
unnamed: R9.1, U1.34 (IO08)
unnamed: R8.2, U1.37 (IO09)
unnamed: R5.1, U1.6 (IO47)
unnamed: J5.2, U1.25 (RST)

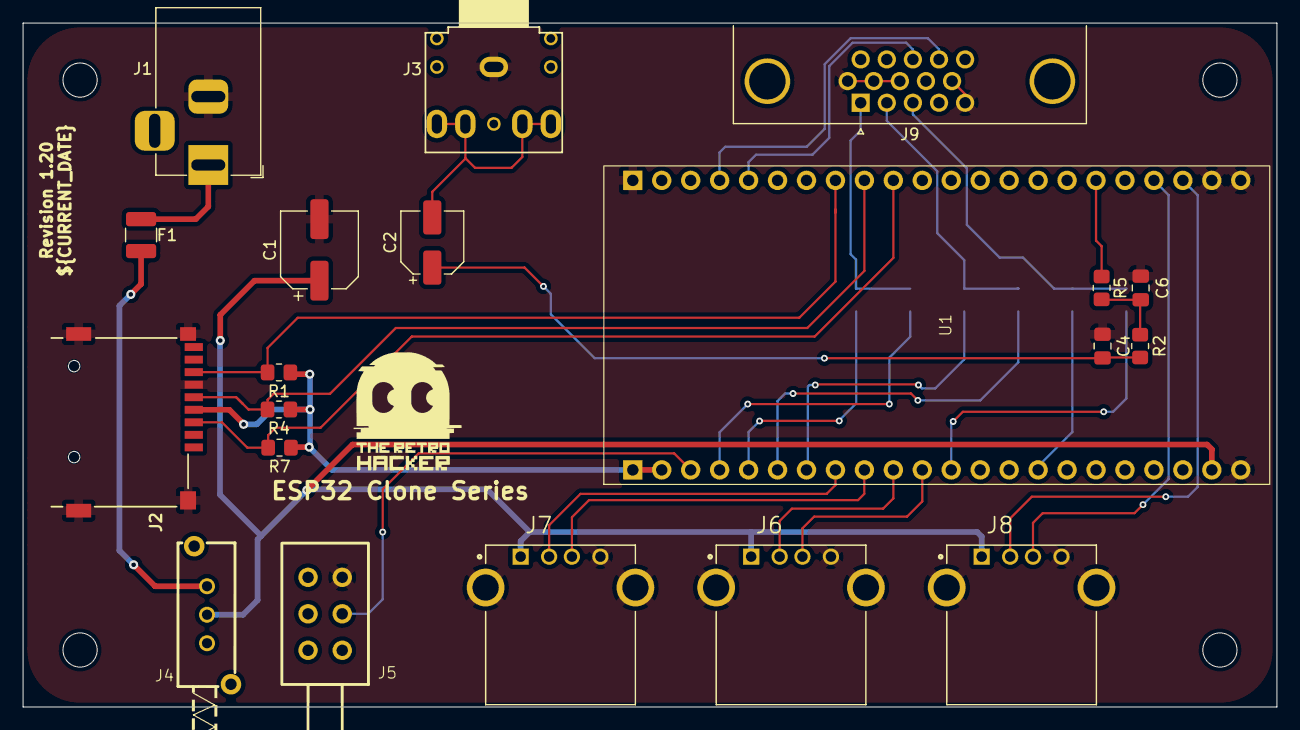
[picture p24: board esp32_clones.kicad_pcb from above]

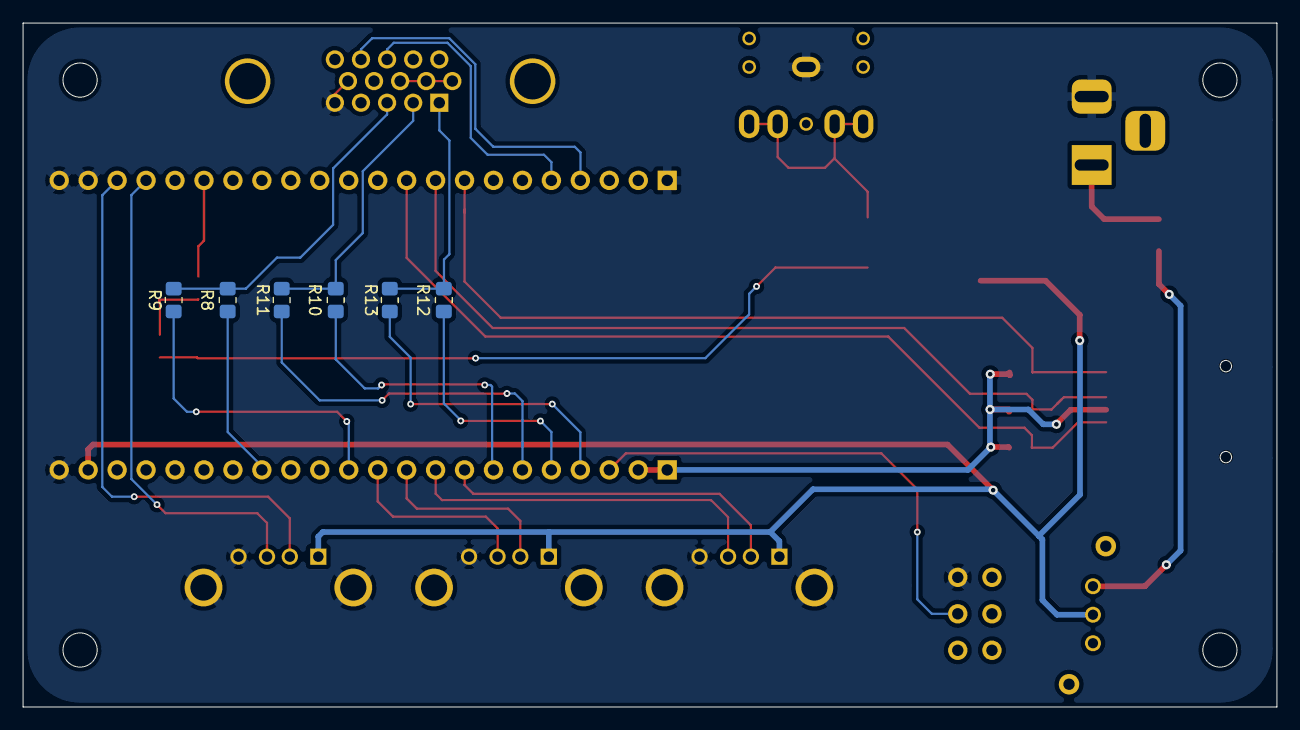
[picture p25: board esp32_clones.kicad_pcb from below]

Board: 2 copper layers, 110.0 x 60.0 mm, 26 parts (6 on the bottom side), 30 nets.

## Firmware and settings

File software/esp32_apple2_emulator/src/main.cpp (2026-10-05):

#include <Arduino.h>
#include <Adafruit_GFX.h>
#include <Preferences.h>
#include <SD_MMC.h>
#include <VGA.h>
#include <esp_heap_caps.h>
#include <memory>
#include <new>
#include <algorithm>
#include "AppleCore.h"
#include "AppleInput.h"
#include "AppleSettings.h"
#include "ApplePlatform.h"
#include "AppleBoard.h"
#include "AppleAudio.h"
#include "AppleKeyboard.h"
#include "AppleJoysticks.h"
#include "AppleJoystickHost.h"
#include "AppleFirmwareUpdate.h"

static VGA video;
static AppleCore machine;
static AppleSettings settings;
static Preferences preferences;
static std::unique_ptr<uint8_t[]> diskData[2];
static bool running = false, audioReady = false, sdReady = false, nvsReady = false;
static bool wantResume = false, audioFailed = false;
static char status[160] = {};
static const char *joystickNames[] = {"Disabled", "Apple paddles"};

class Display : public Adafruit_GFX
{
public:
    Display() : Adafruit_GFX(320, 240) {}
    void drawPixel(int16_t x, int16_t y, uint16_t color) override
    {
        if (x >= 0 && x < 320 && y >= 0 && y < 240)
        {
            video.dot(x * 2, y, color & 255);
            video.dot(x * 2 + 1, y, color & 255);
        }
    }
};
static Display display;

static bool error(const char *message)
{
    snprintf(status, sizeof(status), "%s", message);
    Serial.printf("APPLE: %s\n", status);
    return false;
}

void appleReportError(const char *message)
{
    error(message);
    audioFailed = true;
}

static void text(int x, int y, const char *value, uint8_t color = 255)
{
    display.setCursor(x, y);
    display.setTextColor(color);
    display.print(value);
}

static void frame(const char *title)
{
    video.clear(0);
    display.setTextWrap(false);
    display.setTextSize(1);
    text(8, 8, "ESP32 Clone Series - Apple II");
    text(284, 8, FW_VERSION);
    display.drawFastHLine(8, 21, 304, 255);
    text(8, 29, title, 0xdf);
    display.drawFastHLine(8, 199, 304, 255);
}

static void footer(const char *hint = "Arrows: select  Enter: apply  Esc: back")
{
    text(8, 187, hint);
    const size_t length = strlen(status);
    for (size_t pos = 0; pos < length && pos < 150; pos += 50)
    {
        char line[51] = {};
        memcpy(line, status + pos, std::min<size_t>(50, length - pos));
        text(8, 205 + (pos / 50) * 10, line, 0xdf);
    }
    video.show();
}

static void row(unsigned index, bool selected, const char *label)
{
    if (selected) display.fillRect(6, 46 + index * 12, 308, 10, 0x48);
    text(8, 47 + index * 12, label);
}

static uint8_t key()
{
    for (;;)
    {
        const uint8_t value = AppleKeyboardMenuKey();
        if (value) return value;
        delay(10);
    }
}

static bool back(uint8_t value)
{
    if (value == 69 && running) wantResume = true;
    return value == 41 || value == 69;
}

static const char *baseName(const char *path)
{
    const char *last = strrchr(path, '/');
    return last ? last + 1 : path;
}

static bool confirm(const char *title)
{
    frame(title);
    text(8, 60, "Current machine state may be lost.");
    text(8, 84, "Y: confirm     N / Esc / F12: cancel");
    footer("");
    AppleKeyboardClearEvents();
    for (;;)
    {
        const uint8_t value = key();
        if (value == 28) return true;
        if (value == 17 || value == 41 || value == 69) return false;
    }
}

static bool mountSd()
{
    if (sdReady) return true;
    SD_MMC.setPins(AppleBoard::SdClk, AppleBoard::SdCmd, AppleBoard::SdData);
    sdReady = SD_MMC.begin("/sdcard", true, false, SDMMC_FREQ_DEFAULT, 5);
    if (!sdReady) return error("SD mount failed. Insert a FAT32 card and retry in F12.");
    return true;
}

static bool hasExtension(const char *name, const char *extension)
{
    const size_t length = strlen(name), suffix = strlen(extension);
    return length > suffix && !strcasecmp(name + length - suffix, extension);
}

static bool browse(const char *title, const char *extension, char result[ApplePathSize])
{
    if (!mountSd()) return false;
    char directory[ApplePathSize] = "/";
    unsigned selected = 0;
    AppleKeyboardClearEvents();
    for (;;)
    {
        struct Entry { char name[ApplePathSize]; bool directory; };
        Entry entries[10] = {};
        unsigned total = 0, count = 0;
        const unsigned first = (selected / 10) * 10;
        File folder = SD_MMC.open(directory);
        if (!folder || !folder.isDirectory()) return error("Cannot read SD directory.");
        if (strcmp(directory, "/"))
        {
            if (!first) { snprintf(entries[0].name, ApplePathSize, ".."); entries[0].directory = true; ++count; }
            ++total;
        }
        unsigned visited = 0, skipped = 0;
        for (File entry = folder.openNextFile(); entry; entry = folder.openNextFile())
        {
            if (++visited % 16 == 0) delay(1);
            const char *name = baseName(entry.name());
            if (!strcmp(name, ".") || !strcmp(name, "..") ||
                !strcasecmp(name, "System Volume Information")) continue;
            if (!entry.isDirectory() && !hasExtension(name, extension)) continue;
            char path[ApplePathSize];
            const int length = snprintf(path, sizeof(path), "%s%s%s", directory,
                                         strcmp(directory, "/") ? "/" : "", name);
            if (length < 0 || unsigned(length) >= sizeof(path) || !AppleValidPath(path))
            {
                ++skipped;
                Serial.printf("APPLE browser: invalid/overlong path: %s\n", name);
                continue;
            }
            if (total >= first && count < 10)
            {
                snprintf(entries[count].name, ApplePathSize, "%s", name);
                entries[count++].directory = entry.isDirectory();
            }
            ++total;
        }
        folder.close();
        if (selected >= total && selected) { selected = total ? total - 1 : 0; continue; }
        frame(title);
        for (unsigned i = 0; i < count; ++i)
        {
            char label[52];
            snprintf(label, sizeof(label), "%s%.46s", entries[i].directory ? "> " : "  ", entries[i].name);
            row(i, selected == first + i, label);
        }
        if (!total) text(8, 55, "No matching files.");
        if (skipped) snprintf(status, sizeof(status), "%u unsupported names skipped in %.100s", skipped, directory);
        else snprintf(status, sizeof(status), "%.150s", directory);
        footer("Enter: open  PgUp/PgDn: page  Esc: cancel");
        const uint8_t value = key();
        if (back(value)) return false;
        if (value == 82 && selected) --selected;
        else if (value == 81 && selected + 1 < total) ++selected;
        else if (value == 75) selected = selected >= 10 ? selected - 10 : 0;
        else if (value == 78 && total) selected = std::min(selected + 10, total - 1);
        else if (value == 40 && count)
        {
            const Entry &entry = entries[selected - first];
            if (!strcmp(entry.name, ".."))
            {
                char *slash = strrchr(directory, '/');
                if (slash == directory) directory[1] = 0;
                else *slash = 0;
                selected = 0;
            }
            else
            {
                char path[ApplePathSize];
                const int length = snprintf(path, sizeof(path), "%s%s%s", directory,
                                             strcmp(directory, "/") ? "/" : "", entry.name);
                if (length < 0 || unsigned(length) >= sizeof(path)) return error("SD path is too long.");
                if (entry.directory) { memcpy(directory, path, sizeof(path)); selected = 0; }
                else { snprintf(result, ApplePathSize, "%s", path); status[0] = 0; return true; }
            }
        }
    }
}

static bool readFile(const char *path, size_t maximum, std::unique_ptr<uint8_t[]> &data, size_t &size)
{
    if (!AppleValidPath(path)) return error("Invalid SD path.");
    if (!mountSd()) return false;
    File file = SD_MMC.open(path);
    if (!file || file.isDirectory())
    {
        snprintf(status, sizeof(status), "Cannot open %.130s", path);
        Serial.println(status);
        return false;
    }
    const size_t length = file.size();
    if (!length || length > maximum) return error("File is empty or exceeds the supported size.");
    std::unique_ptr<uint8_t[]> candidate(new (std::nothrow) uint8_t[length]);
    if (!candidate) return error("Not enough memory to stage SD file.");
    for (size_t pos = 0; pos < length;)
    {
        const size_t chunk = std::min<size_t>(4096, length - pos);
        if (file.read(candidate.get() + pos, chunk) != chunk) return error("SD read failed; previous selection kept.");
        pos += chunk;
        delay(1);
    }
    if (file.size() != length) return error("SD file changed during loading.");
    data = std::move(candidate);
    size = length;
    return true;
}

struct BootFiles
{
    std::unique_ptr<uint8_t[]> rom, slot, disks[2];
    size_t romSize = 0;
};

static bool stageBoot(BootFiles &files)
{
    if (!AppleValidSettings(settings)) return error("Invalid machine configuration.");
    const size_t expected = settings.model == AppleModel::IIe ? 16384 : 12288;
    if (!readFile(settings.rom[unsigned(settings.model)], expected, files.rom, files.romSize)) return false;
    if (files.romSize != expected) return error("ROM size mismatch: II+ = 12288; original IIe = 16384.");
    size_t slotSize = 0;
    if (!readFile(settings.diskRom, 256, files.slot, slotSize)) return false;
    if (slotSize != 256) return error("Disk II ROM must be exactly 256 bytes.");
    for (unsigned drive = 0; drive < 2; ++drive)
    {
        if (!settings.disk[drive][0]) continue;
        size_t size = 0;
        if (!readFile(settings.disk[drive], AppleDisk::ImageSize, files.disks[drive], size)) return false;
        AppleDisk check;
        if (!check.attach(files.disks[drive].get(), size, status, sizeof(status))) { Serial.println(status); return false; }
    }
    return true;
}

static bool saveSettings()
{
    if (!nvsReady) return error("NVS unavailable; settings were not saved.");
    if (!AppleJoystickHostPause()) return error("Cannot pause joystick host for NVS write.");
    const bool saved = preferences.putBytes("boot", &settings, sizeof(settings)) == sizeof(settings);
    AppleJoystickHostResume();
    if (!saved) return error("NVS write failed; settings were not saved.");
    snprintf(status, sizeof(status), "Complete boot configuration saved.");
    return true;
}

static bool boot(bool save, bool onlySave = false)
{
    BootFiles files;
    if (!stageBoot(files) || (save && !saveSettings())) return false;
    if (onlySave) return true;
    if (!machine.boot(files.rom.get(), files.romSize, files.slot.get(), 256, settings.model, status, sizeof(status)))
    {
        Serial.println(status);
        return false;
    }
    for (unsigned drive = 0; drive < 2; ++drive)
    {
        machine.disks[drive].eject();
        diskData[drive] = std::move(files.disks[drive]);
        if (diskData[drive] && !machine.disks[drive].attach(diskData[drive].get(), AppleDisk::ImageSize, status, sizeof(status)))
        {
            running = false;
            Serial.println(status);
            return false;
        }
    }
    running = true;
    status[0] = 0;
    return true;
}

static void attachDisk(unsigned drive)
{
    char path[ApplePathSize] = {};
    if (!browse("Select NIB disk (read-only)", ".nib", path)) return;
    std::unique_ptr<uint8_t[]> candidate;
    size_t size = 0;
    if (!readFile(path, AppleDisk::ImageSize, candidate, size)) return;
    if (!machine.disks[drive].attach(candidate.get(), size, status, sizeof(status)))
    {
        Serial.println(status);
        return;
    }
    diskData[drive] = std::move(candidate);
    snprintf(settings.disk[drive], ApplePathSize, "%s", path);
    snprintf(status, sizeof(status), "Drive %u mounted read-only. Cold boot to start a boot disk.", drive + 1);
}

static void mediaMenu()
{
    unsigned selected = 0;
    for (;;)
    {
        frame("Media");
        char label[60];
        for (unsigned drive = 0; drive < 2; ++drive)
        {
            snprintf(label, sizeof(label), "Drive %u: %.40s", drive + 1,
                     settings.disk[drive][0] ? baseName(settings.disk[drive]) : "<empty>");
            row(drive, selected == drive, label);
        }
        row(2, selected == 2, "Save complete boot configuration");
        row(3, selected == 3, "Reboot and save configuration");
        row(4, selected == 4, "Reboot without saving");
        text(8, 119, "Slot 6 / 35-track NIB / write-protected");
        footer("Enter: select  Del: eject  F12: resume");
        const uint8_t value = key();
        if (back(value)) return;
        if (value == 82) selected = (selected + 4) % 5;
        else if (value == 81) selected = (selected + 1) % 5;
        else if (value == 76 && selected < 2)
        {
            machine.disks[selected].eject();
            diskData[selected].reset();
            settings.disk[selected][0] = 0;
            snprintf(status, sizeof(status), "Drive %u ejected.", selected + 1);
        }
        else if (value == 40)
        {
            if (selected < 2) attachDisk(selected);
            else if (selected == 2) boot(true, true);
            else if (confirm("Cold reboot selected configuration?") && boot(selected == 3))
            {
                wantResume = true;
                return;
            }
        }
        if (wantResume) return;
    }
}

static bool samePad(const AppleJoystickSnapshot &a, const AppleJoystickSnapshot &b)
{
    return b.connected && a.generation == b.generation && a.vid == b.vid && a.pid == b.pid &&
           a.endpoint == b.endpoint && a.length == b.length;
}

static void calibrate(unsigned port)
{
    AppleJoystickSnapshot identity;
    AppleJoystickSnapshotFor(port, identity);
    if (!identity.connected || !identity.length) { error("Connect a low-speed USB joystick with reports first."); return; }
    const char *poses[] = {"Release all controls", "Hold UP", "Hold RIGHT", "Hold DOWN", "Hold LEFT", "Hold button A", "Hold button B"};
    AppleJoystickSample samples[7] = {};
    for (unsigned pose = 0; pose < 7; ++pose)
    {
        frame("Joystick calibration");
        text(8, 55, poses[pose]);
        text(8, 80, "Keep holding until the next prompt.");
        footer("Enter: capture  Esc/F12: cancel");
        AppleKeyboardClearEvents();
        uint8_t value;
        do { value = key(); if (back(value)) return; } while (value != 40);
        uint8_t baseline[8] = {};
        bool first = true;
        uint32_t sequence = 0;
        unsigned freshReports = 0;
        AppleJoystickSnapshot current;
        AppleJoystickSnapshotFor(port, current);
        sequence = current.sequence;
        const uint32_t start = millis();
        while (millis() - start < 600)
        {
            if (back(AppleKeyboardMenuKey())) return;
            AppleJoystickSnapshotFor(port, current);
            if (!samePad(identity, current)) { error("Joystick changed; calibration cancelled."); return; }
            if (millis() - start >= 250 && current.sequence != sequence)
            {
                sequence = current.sequence;
                ++freshReports;
                if (first) { memcpy(baseline, current.report, identity.length); first = false; }
                if (!pose)
                    for (unsigned i = 0; i < identity.length; ++i)
                        samples[pose].changed[i] |= baseline[i] ^ current.report[i];
                memcpy(samples[pose].bytes, current.report, identity.length);
            }
            delay(10);
        }
        if (!freshReports) { error("No fresh joystick reports during capture; retry."); return; }
    }
    AppleJoystickMapping mapping = {};
    if (!AppleBuildJoystickCardinalMapping(identity.length, samples, mapping, status, sizeof(status)) ||
        !AppleJoystickSave(port, identity, mapping, status, sizeof(status))) Serial.println(status);
}

static void joystickMenu()
{
    unsigned selected = 0;
    for (;;)
    {
        frame("USB joysticks");
        for (unsigned port = 0; port < 2; ++port)
        {
            AppleJoystickSnapshot pad;
            AppleJoystickSnapshotFor(port, pad);
            char label[64];
            snprintf(label, sizeof(label), "Port %u: %s", port + 1, joystickNames[unsigned(settings.joystick[port])]);
            row(port * 3, selected == port * 3, label);
            snprintf(label, sizeof(label), "Calibrate %u: %s  %02X", port + 1, !pad.connected ? "disconnected" :
                     pad.calibrated ? "calibrated" : "needs calibration", pad.buttons);
            row(port * 3 + 1, selected == port * 3 + 1, label);
            row(port * 3 + 2, selected == port * 3 + 2, "Clear saved calibration");
            snprintf(label, sizeof(label), "%u VID %04X PID %04X report %u bytes", port + 1, pad.vid, pad.pid, pad.length);
            text(8, 134 + port * 12, label);
        }
        footer("Enter: change  Esc: back  F12: resume");
        uint8_t value = 0;
        const uint32_t start = millis();
        while (!value && millis() - start < 100) { value = AppleKeyboardMenuKey(); delay(10); }
        if (back(value)) return;
        if (value == 82) selected = (selected + 5) % 6;
        else if (value == 81) selected = (selected + 1) % 6;
        else if (value == 40 || value == 79 || value == 80)
        {
            const unsigned port = selected / 3;
            if (selected % 3 == 0)
                settings.joystick[port] ^= 1;
            else if (selected % 3 == 1 && value == 40) calibrate(port);
            else if (selected % 3 == 2 && value == 40 && confirm("Clear this joystick calibration?"))
                AppleJoystickClear(port, status, sizeof(status));
        }
        if (wantResume) return;
    }
}

static void progress(const char *stage, uint8_t percent)
{
    frame("Firmware update - keep power connected");
    text(8, 58, stage);
    display.drawRect(8, 78, 304, 14, 255);
    display.fillRect(10, 80, 300 * percent / 100, 10, 0xdf);
    video.show();
}
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
void loop()
{
    static uint32_t lastReport = millis(), measuredFrames = 0, renderedFrames = 0;
    static uint64_t cpuMicros = 0, videoMicros = 0, copyMicros = 0, audioMicros = 0;
    bool openMenu = !running || audioFailed;
    for (uint8_t value = AppleKeyboardMenuKey(); value; value = AppleKeyboardMenuKey())
        if (value == 69) openMenu = true;
    if (openMenu)
    {
        if (audioFailed) { settings.sound = 0; audioFailed = false; }
        menu();
        present();
        lastReport = millis();
        measuredFrames = 0;
        renderedFrames = 0;
        cpuMicros = videoMicros = copyMicros = audioMicros = 0;
    }
    const uint32_t start = micros();
    uint8_t report[8];
    AppleKeyboardReport(report);
    uint16_t pads = AppleJoysticksRead();
    if (!settings.joystick[0]) pads &= 0xff00;
    if (!settings.joystick[1]) pads &= 0x00ff;
    bool held = false;
    for (unsigned i = 2; i < 8; ++i) held |= AppleAscii(report[i], report[0], false) >= 0;
    machine.input(held, report[0], pads);
    uint8_t character;
    if (!machine.keyPending() && AppleKeyboardCharacter(character)) machine.key(character);
    int16_t samples[AppleCore::MaxSamples];
    unsigned count = 0;
    const bool draw = machine.frames % (settings.frameSkip + 1) == 0;
    const uint32_t cpuStart = micros();
    machine.runFrame(nullptr, samples, count, settings.monochrome);
    const uint32_t cpuEnd = micros();
    cpuMicros += cpuEnd - cpuStart;
    if (draw && machine.needsRender(settings.monochrome))
    {
        const uint32_t copied = present();
        videoMicros += (micros() - cpuEnd) - copied;
        copyMicros += copied;
        ++renderedFrames;
    }
    const uint32_t audioStart = micros();
    if (audioReady && settings.sound)
    {
        for (unsigned i = 0; i < count; ++i) samples[i] = samples[i] * settings.volume / 100;
        AppleAudioSubmit(samples, count);
    }
    audioMicros += micros() - audioStart;
    const uint32_t target = AppleCore::FrameMicros;
    const uint32_t elapsed = micros() - start;
    if (elapsed < target)
    {
        const uint32_t remaining = target - elapsed;
        if (remaining >= 1000) delay(remaining / 1000);
        while (micros() - start < target) delayMicroseconds(10);
    }
    else delay(1);
    ++measuredFrames;
    const uint32_t now = millis();
    if (now - lastReport >= 5000)
    {
        Serial.printf("APPLE speed: %.2f emulated fps, target %.2f, rendering 1/%u\n",
                      measuredFrames * 1000.0 / (now - lastReport),
                      1000000.0 / target, settings.frameSkip + 1);
        const double millisecondsPerFrame = 1000.0 * measuredFrames;
        Serial.printf("APPLE timing: CPU %.2f ms, video %.2f ms, copy %.2f ms, audio %.2f ms; draws %u/%u; PC %04X, track %u, emulated %.1f s\n",
                      cpuMicros / millisecondsPerFrame, videoMicros / millisecondsPerFrame,
                      copyMicros / millisecondsPerFrame, audioMicros / millisecondsPerFrame,
                      renderedFrames, measuredFrames, m6502_pc(&machine.cpu), machine.disks[0].track(),
                      double(machine.cycles) / AppleCore::ClockRate);
        lastReport = now;
        measuredFrames = 0;
        renderedFrames = 0;
        cpuMicros = videoMicros = copyMicros = audioMicros = 0;
    }
}

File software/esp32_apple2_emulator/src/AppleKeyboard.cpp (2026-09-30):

/******************************************************************************
 * Native USB host adapted from CP400UsbKeyboard by The Retro Hacker.
 * CP400 code and modifications copyright (c) 2026 The Retro Hacker
 *
 * Permission is granted for personal, non-commercial use only.
 * Commercial use, distribution, sublicensing, or modification
 * for commercial purposes is strictly prohibited without
 * prior written permission from the author.
 * Please, keep this in the source code.
 * All rights reserved.
 ******************************************************************************/
#include "AppleKeyboard.h"
#include "AppleInput.h"

#include <Arduino.h>
#include <string.h>
#include "freertos/FreeRTOS.h"
#include "freertos/task.h"
#include "usb/usb_host.h"

namespace {
constexpr uint8_t ReportSize = 8;
constexpr uint8_t EventCapacity = 32;
portMUX_TYPE stateLock = portMUX_INITIALIZER_UNLOCKED;
uint8_t matrixState[16] = {
    0xff, 0xff, 0xff, 0xff, 0xff, 0xff, 0xff, 0xff,
    0xff, 0xff, 0xff, 0xff, 0xff, 0xff, 0xff, 0xff
};
uint8_t events[EventCapacity];
uint8_t appleReport[ReportSize] = {};
uint8_t eventHead = 0, eventCount = 0;
uint8_t characters[EventCapacity], characterHead = 0, characterCount = 0;
bool emulationInput = false, capsLock = true;
uint8_t repeatKey = 0;
uint32_t repeatAt = 0;
bool connected = false;
bool started = false, starting = false;

// Only HostTask owns USB state; callbacks execute synchronously in its event pump.
usb_host_client_handle_t client = nullptr;
usb_device_handle_t device = nullptr;
usb_transfer_t *reportTransfer = nullptr, *controlTransfer = nullptr;
uint8_t interfaceNumber = 0, endpointAddress = 0, pendingAddress = 0;
uint16_t maxPacket = ReportSize;
bool claimed = false, stopping = false, cancellationRequested = false;
bool reportPending = false, controlPending = false;
bool malformedReportLogged = false;
uint8_t previousReport[ReportSize] = {};
enum class Stage { None, Protocol, Idle, Ready };
Stage stage = Stage::None;
TickType_t controlStarted = 0;

void PublishDisconnected()
{
    portENTER_CRITICAL(&stateLock);
    connected = false;
    memset(appleReport, 0, sizeof(appleReport));
    memset(matrixState, 0xff, sizeof(matrixState));
    eventHead = eventCount = 0;
    characterHead = characterCount = 0;
    portEXIT_CRITICAL(&stateLock);
    memset(previousReport, 0, sizeof(previousReport));
    repeatKey = 0;
}

void Fail(const char *operation, esp_err_t error)
{
    Serial.printf("APPLE USB keyboard: %s failed (%s)\n", operation, esp_err_to_name(error));
    stopping = true;
    PublishDisconnected();
}

void Press(uint8_t *matrix, unsigned row, unsigned bit)
{
    matrix[row] &= static_cast<uint8_t>(~(1u << bit));
}
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

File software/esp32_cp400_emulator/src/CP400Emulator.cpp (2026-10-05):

/******************************************************************************
 * Project      : esp32_cp400_emulator
 * File         : CP400Emulator.cpp
 * Last Updated : 2026-08-17
 *
 * Description  : CP400 emulator main code (CPU core, video, disk, peripherals)
 *
 * Original work copyright (c) 2026 Cedric Beaudoin
 * CP400 code and modifications copyright (c) 2026 The Retro Hacker
 *
 * Permission is granted for personal, non-commercial use only.
 * Commercial use, distribution, sublicensing, or modification
 * for commercial purposes is strictly prohibited without
 * prior written permission from the author.
 * Please, keep this in the source code.
 * All rights reserved.
 ******************************************************************************/




#include <Arduino.h>
#include "mc6809.hpp"
#include "esp_timer.h"
#include "esp_system.h"

#include "CP400Emulator.h"

#include "ESP32S3vga.h"
#include <GfxWrapper.h>
#include <Fonts/FreeMonoBoldOblique24pt7b.h>
#include <Fonts/FreeSerif24pt7b.h>
#include <Fonts/FreeMono9pt7b.h>



//----------------------------USB STACK-------------------------------------

#include <ESP32-USB-Soft-Host.h>
#include "CP400Input.h"
#include "CP400UsbKeyboard.h"
#define KEY_SHIFT_LEFT




USB_DEVICES_CTRL USB_DEV_CONTROL;



  //Each pin pair is one USB connector: P1 joystick 1, P2 joystick 2.
  //The keyboard no longer uses the soft host. It runs on the USB-OTG controller
  //through GPIO19 and GPIO20 so full speed keyboards enumerate, which the
  //bit-banged stack could never do. See CP400UsbKeyboard.cpp.
  #define DP_P0  -1
  #define DM_P0  -1
  #define DP_P1  16
  #define DM_P1  15
  #define DP_P2  18
  #define DM_P2  17
  #define DP_P3  -1
  #define DM_P3  -1

extern USB_DEVICES_CTRL USB_DEV_CONTROL;

extern void Setup_USB(void);





//-----------------------------------------------------------



#define LED_PORT_ANODE 45
#define LED_PORT_CATHODE 46

#define LED_PORT_CATHODE_HI() GPIO.out1_w1ts.val = (1 << (LED_PORT_CATHODE - 32));  // Set HIGH
#define LED_PORT_CATHODE_LOW() GPIO.out1_w1tc.val = (1 << (LED_PORT_CATHODE - 32));  // Set LOW

#define LED_PORT_ANODE_HI() GPIO.out1_w1ts.val = (1 << (LED_PORT_ANODE - 32));  // Set HIGH
#define LED_PORT_ANODE_LOW()  GPIO.out1_w1tc.val = (1 << (LED_PORT_ANODE - 32));  // Set LOW

void inline DISKETTE_LED_ON(void)
{
  LED_PORT_CATHODE_HI();
  LED_PORT_ANODE_LOW();
}
void inline DISKETTE_LED_OFF(void)
{
  LED_PORT_CATHODE_LOW();
  LED_PORT_ANODE_HI();
}
void inline DISKETTE_LED_FLOAT(void)
{
  LED_PORT_CATHODE_LOW();
  LED_PORT_ANODE_LOW();
}




uint8_t uint8_t_VarGlobal;
uint8_t DEBUGloop1, DEBUGloop2;
void Debug1Toggle(void)
{
  if ((DEBUGloop1 & 0b00000001) == 0)
  {
    GPIO.out_w1ts = (1 << DEBUG1);
  }
  else
  {
    GPIO.out_w1tc = (1 << DEBUG1);
  }
  DEBUGloop1++;
}
void Debug2Toggle(void)
{
  if ((DEBUGloop2 & 0b00000001) == 0)
  {
    GPIO.out_w1ts = (1 << DEBUG2);
  }
  else
  {
    GPIO.out_w1tc = (1 << DEBUG2);
  }
  DEBUGloop2++;
}

void Debug2Hi(void)
{
    GPIO.out_w1ts = (1 << DEBUG2);
}

void Debug2Low(void)
{
    GPIO.out_w1tc = (1 << DEBUG2);
}



uint8_t ResetVectors[16] = {0xA6, 0x81, 0x01, 0x00, 0x01, 0x03, 0x01, 0x0F,
	0x01, 0x0C, 0x01, 0x06, 0x01, 0x09, 0xA0, 0x27};




bool CPU_in_WAIT_STATE = false;



File file;
bool SD_Card_Mounted = false;


#ifndef ISR_CORE
char text_buffer[150];
#endif



uint8_t *MENU_Backup = (uint8_t *)heap_caps_malloc(640*250, MALLOC_CAP_SPIRAM);
uint8_t *MENU_BackupPage2 = (uint8_t *)heap_caps_malloc(640*250, MALLOC_CAP_SPIRAM);
#define DISK_SIZE 161280

uint8_t *RAM_Disk0 = (uint8_t *)heap_caps_malloc(161280, MALLOC_CAP_SPIRAM);
uint8_t *RAM_Disk1 = (uint8_t *)heap_caps_malloc(161280, MALLOC_CAP_SPIRAM);
uint8_t *RAM_Disk2 = (uint8_t *)heap_caps_malloc(161280, MALLOC_CAP_SPIRAM);
uint8_t *RAM_Disk3 = (uint8_t *)heap_caps_malloc(161280, MALLOC_CAP_SPIRAM);
#ifdef PSRAM_EMU
uint8_t *rom = (uint8_t *)heap_caps_malloc(32769, MALLOC_CAP_SPIRAM);
uint8_t *memory = (uint8_t *)heap_caps_malloc(65536, MALLOC_CAP_SPIRAM);
#else
uint8_t rom[32769];
uint8_t memory[65536];
#endif



SpecialFunctionStruct sf;

struct DiskAccessStruct
{
  uint8_t TrackPos;
  uint8_t DriveSelected;
  uint8_t MotorOnOff;
  uint8_t SectorPos;
  uint8_t DRIVE_COMMAND;
  uint8_t DataRegisterValue;
  uint32_t DSK_FILE_DataPTR;
  bool IsinReadProcess;
  bool IsInWriteProcess;
  bool NMI_Int_Started;
  uint8_t NMI_Delay;    //To Allow the CP400 to read the last byte from the FD502 before the NMI.
  uint16_t RW_Process_ByteRemainingCounter;
};

DiskAccessStruct DiskAccess;


DriveStruct Disk_Drive;
DiskRomSelection selectedDiskRom = DiskRomSelection::CP400;



  class cpu_t : public mc6809 
{
  public:
      uint8_t read8(uint16_t address) const 
      {
        uint8_t t_data;
        ManagePeripherals_Read(address);
      if (!sf.CP400_32K_UPPER_ENABLED)
      {
        if ((address > 0x7fff))
        {

          return rom[address - ROM_OFFSET];
        }
        else
        {
          return memory[address];
        }

      }
      else
      {
        if ((address > 0xdfff))
        {
          
          return rom[address - ROM_OFFSET];
        }
        else
        {
          return memory[address];
        }
      }

        return 0;
      }

      

      void write8(uint16_t address, uint8_t value) const 
      {
          ManagePeripherals_Write(address , value);


        if (!sf.CP400_32K_UPPER_ENABLED)
        {
          if (address >0x7fff)
          {
              
              //rom[address - 0x8000] = value;
          
          } 
          else
          {
              memory[address] = value;
          }
        }
        else
        {
              memory[address] = value;
        }



          
        }


};



bool ReadCP400DiskImage(const char* filename, uint8_t DriveNumber)
{
    if (!SD_Card_Mounted)
    {
      return false;
    }
    
    
    size_t bytesRead;
    File f = SD_MMC.open(filename, FILE_READ);
    if(!f)
    {
#ifdef DEBUG_PRINT    
        Serial.print("Failed to open file: ");
        Serial.println(filename);
#endif
        return false;
    }

    
    switch (DriveNumber)
    {
    case 0:
      bytesRead = f.read(RAM_Disk0, DISK_SIZE);
    break;
    case 1:
      bytesRead = f.read(RAM_Disk1, DISK_SIZE);
    break;
    case 2:
      bytesRead = f.read(RAM_Disk2, DISK_SIZE);
    break;
    case 3:
      bytesRead = f.read(RAM_Disk3, DISK_SIZE);
    break;
    
    default:
      break;
    }
    
    

#ifdef DEBUG_PRINT    
    Serial.print("Read ");
    Serial.print(bytesRead);
    Serial.print(" bytes into RAM_Disk ");
    Serial.println(DriveNumber);
#endif
    f.close();
    

    return true;
}
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

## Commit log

2026-06-25 Add font data and testing documentation
    - Added CoCO2_3_Fonts.txt containing font data for the emulator.
    - Created README file in the test directory to explain the purpose of the directory and provide information on PlatformIO Unit Testing.
    - Introduced ScrapBook.txt with various BASIC programs and notes related to disk transactions and graphics modes.
    [esp32_clones.kicad_pcb, esp32_clones.kicad_sch]
2026-06-30 Refactor code structure for improved readability and maintainability
    [esp32_clones.kicad_pcb, esp32_clones.kicad_sch]
2026-08-02 Add production files for ESP32 clones including BOM, designators, netlist, and positions
    - Created bom.csv to define components and their specifications.
    - Added designators.csv to map designators to their respective values.
    - Introduced netlist.ipc for electrical connections and layout.
    - Added positions.csv to specify component placements on the PCB.
    [bom.csv, designators.csv, esp32_clones.kicad_pcb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]
2026-08-17 Fix to the hardware: VSYNC pin from 0 to 1
    [esp32_clones.kicad_pcb]
2026-08-17 Remove unused font and test files from the esp32_cp400_emulator project to clean up the repository.
2026-09-02 - Drove the audio output in stereo, with the left channel on GPIO47 and the right channel on GPIO48. The CP400 sound source is mono, so both channels carry the same signal. - Raised the audio carrier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
    [esp32_clones.kicad_pcb, esp32_clones.kicad_sch]
2026-09-07 - New board and small adjustments for sound on CP400 emulator
    [bom.csv, designators.csv, esp32_clones.kicad_pcb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]
2026-09-07 - Added an independent, non-commercial fMSX-based MSX1/MSX2/MSX2+ firmware for the shared ESP32-S3 N16R8 board. - Matched the existing board's VGA, native USB keyboard, one-bit SD/MMC, and GPIO47 mon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
    [partitions.csv]
2026-09-07 - Added SD-card cartridge ROM selection and ejection for emulated slots 1 and 2, applied the selected cartridges on cold boot, and saved both assignments with the boot defaults while preserving older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
    [MsxFirmwareUpdate.cpp, MsxKeyboard.cpp, main.cpp]
2026-09-09 - Added independent low-speed USB gamepad input on the two joystick connectors, mapped directions and two fire buttons to MSX joystick ports 1 and 2, and released input when a pad disconnected. - Add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
    [main.cpp]
2026-09-09 - Made F12 mute and Sound Off fade GPIO47 to a steady low output and stop its sample timer, rather than continuing a 50% PWM carrier. - Faded sustained silent audio to a non-switching GPIO47 output, 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
    [MsxAudio.cpp, main.cpp]
2026-09-11 Add Panasonic model support and enhance file browser tests
    - Implemented Panasonic model handling in Import-Roms.ps1, allowing for the addition of FS-A1WSX, FS-A1F, and FS-A1FX profiles with appropriate BIOS and ROM configurations.
    - Enhanced FileBrowserTests.cpp to include tests for hidden Windows metadata folders and various ROM/FLH filtering scenarios, ensuring robust pagination and error handling.
    - Introduced new animation tests in animation.cpp and vdp_animation.cpp to validate graphical output and sprite behavior in the emulator.
    - Created ProfileLoadingTests.cpp to verify the loading and validation of MSX profiles, including checks for ambiguous and malformed paths.
    - Added SD_MMC.h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
2026-09-11 Enhance boot progress display and rendering management during initialization, adding a progress gauge for startup stages and improving frame pacing responsiveness.
2026-09-12 Add USB host support and update README with local firmware dependencies
    - Introduced usb_host.h to implement USB host functionality with various callback mechanisms.
    - Documented local firmware dependencies in README.md, detailing sources and versions for board definitions, VGA, graphics, peripheral I/O, and low-speed USB.
2026-09-12 feat: Enhance media handling in MSX emulator
    - Added support for disk and tape media paths in the emulator.
    - Implemented validation for selected disks and tapes.
    - Updated settings structure to include disk and tape paths.
    - Enhanced the save and load settings functionality to handle new media paths.
    - Introduced a media menu for attaching and managing disks and tapes.
    - Updated tests to cover new media functionalities and ensure proper validation.
    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
2026-09-12 Refactor media handling and menu structure
    - Updated media validation to support both read-only and writable modes for disks and tapes.
    - Consolidated media menu options into a single entry for ROMs, disks, and tapes.
    - Enhanced error reporting for media attachment failures and validation issues.
    - Introduced new functions for boot selection and settings validation.
    - Added comprehensive tests for media menu interactions and edge cases.
    - Improved user feedback in the menu regarding media attachment status and actions.
    [main.cpp]
2026-09-12 Add unit tests for MapperDatabase and PowerShell script for testing
    - Introduced `MapperDatabaseTests.cpp` to validate mapper functionality against the ROM database.
    - Implemented assertions to check mapper IDs and handle known signatures.
    - Added a PowerShell script `Test-MapperDatabase.ps1` to automate the compilation and execution of the tests.
    - The script compiles necessary C and C++ files, links them, and runs the tests, with an option to specify a Tiny Magic ROM.
2026-09-12 Add audio profile support for MSX emulation
    - Introduced `AudioProfiles.h` and `AudioProfiles.cpp` to manage audio profiles for MSX emulation.
    - Implemented functions to validate audio profiles and resolve paths for FM BIOS files.
    - Added tests for audio core functionality in `audio_core.cpp`, ensuring proper handling of various audio profiles.
    - Created PowerShell script `Import-AudioBios.ps1` for importing FM BIOS files with validation checks.
    - Added regression tests for mapper overrides in `mapper_override_regression.h`.
    - Updated `MsxMappers.h` to define mappers used in the MSX system.
    - Enhanced error handling and validation in audio profile resolution.
    [main.cpp]
2026-09-13 Enhance disk management and error handling in MSX emulator
    - Introduced DiskLoadLastError function to retrieve the last disk load error message.
    - Improved ChangeDisk function to provide detailed error reporting during disk operations.
    - Added support for buffered disk reads to enhance performance and reliability.
    - Updated media selection menu to streamline disk and tape management.
    - Enhanced test cases for media handling, including regression tests for disk read failures.
    - Refactored media menu to support new media types and improve user experience.
    - Ensured compatibility with existing media formats and added checks for media validity.
    [main.cpp]
2026-09-13 Refactor sprite collision detection and video presentation
    - Introduced a new `WorkProfile` class to track performance metrics for different sections of the emulator, including VDP, drawing, blitting, sprites, audio, and input.
    - Updated the `msxPresent` function to accept a stride parameter, allowing for flexible row sizes in video frames.
    - Enhanced sprite collision detection by implementing optimized bit manipulation techniques for checking sprite overlaps.
    - Added tests for sprite collision and video rendering to ensure correctness and performance improvements.
    - Refactored related functions and structures to support the new collision detection logic and video presentation changes.
    - Imp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
    [main.cpp]
2026-09-26 - Added TK95 and 48 KiB TK90X emulation on the shared ESP32-S3 N16R8 CP400/MSX hardware. - Added an F12 menu for ROM and machine selection, 50/60 Hz Microdigital timing, Portuguese/Spanish ROM select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
    [partitions.csv]
2026-09-30 - Added standalone Apple II+ and original Apple IIe profiles with 64 KiB and 128 KiB of RAM respectively, using user-supplied machine and Disk II ROMs from the `apple2/bios` SD folder. - Added full-w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
    [partitions.csv]
2026-09-30 - Moved the 6502 decoder and memory-access hot path into internal instruction RAM to reduce flash-cache overhead during emulation. - Rendered display rows in internal RAM before copying them to PSRAM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
    [AppleCore.cpp, main.cpp]
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2026-10-03 Add new STEP file for ESP32 clones hardware
    [APPLE2_1_3_scale.stl, APPLE2_1_3_scale_open.stl, APPLE2_1_3_scale_open2.stl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]
2026-10-04 Update README with Compact Classic C2 details and add new STL files for hardware cases
    [classic_base.stl, classic_upper.stl]
2026-10-05 Add ESP32 CP400 firmware emulator with OTA update support
    - Implemented Test-FirmwareCompatibility.ps1 to validate firmware compatibility across multiple projects.
    - Created README.md for the ESP32 CP400 emulator detailing hardware setup, build instructions, and firmware update procedures.
    - Added partitions.csv defining the memory layout for the ESP32 CP400 firmware.
    - Developed Cp400Flh.cpp and Cp400Flh.h for handling firmware image validation and installation.
    - Introduced comprehensive unit tests in FirmwareUpdateTests.cpp to ensure firmware update functionality.
    - Added Test-FirmwareUpdate.ps1 for compiling and running firmware update tests with g++.
    [PS-12E05_cap.stl, esp32_clones.kicad_pcb, partitions.csv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]
2026-10-06 Update STL and PNG files for HB-8000 hardware cases
    [classic_base.stl, classic_upper.stl]
2026-10-08 Sony and Panasonic cases, optimization to print hb-8000 and the other cases. Tests with K2.
    [FS-A1ST_1_3_scale.stl, FS-A1ST_1_3_scale_open.stl, HB-F1XD_1_3_scale.stl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]
2026-10-09 Apple2 inspired case
    [apple2_base.stl, apple2_keyboard_optimized.stl, apple2_upper.stl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]
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2026-10-27 Enhance file validation and error reporting in MSX emulator
    - Introduced detailed error reporting for cartridge, disk, and tape file validation, including full SD paths and errno descriptions.
    - Updated `MsxValidateCartridge`, `MsxValidateDisk`, and `MsxValidateTape` functions to provide comprehensive diagnostics on file access issues.
    - Added new tests for file diagnostics to ensure robust error handling and validation.
    - Modified Makefile to include a new PowerShell script for file diagnostics testing.
    - Enhanced README documentation to reflect changes in error reporting and diagnostics.
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2026-10-28 Add comprehensive tests for audio output, file browsing, game audio, memory hooks, and sound menu functionality
    - Implemented AudioOutputTests to validate PWM audio output and diagnostics.
    - Created FileBrowserFrontendTests to ensure correct navigation and file selection in the file browser.
    - Added GameAudioTests to verify audio playback and clipping behavior during game execution.
    - Developed MemoryHooks tests to monitor memory allocation and ensure limits are respected.
    - Introduced SoundMenuTests to validate sound settings application and menu interactions.
    - Added necessary audio stubs and test scripts for seamless testing environment setup.
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2026-10-29 Add MacFloppy class for floppy disk image handling
    - Implemented MacFloppy class to manage floppy disk images, including opening, closing, and checking if an image is inserted.
    - Added error handling for file operations and memory allocation.
    - Created unit tests for MacFloppy to validate functionality with various floppy disk image sizes and formats.
    - Ensured compatibility with both Arduino and non-Arduino environments.

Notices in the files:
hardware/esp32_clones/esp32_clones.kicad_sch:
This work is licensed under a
